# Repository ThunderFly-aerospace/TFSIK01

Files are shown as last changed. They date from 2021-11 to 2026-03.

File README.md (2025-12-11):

# TFSIK01 - Dual Antenna diversity telemetry modem with a high noise immunity

The TFSIK01 is a high-end open-source hardware design of a UAV modem utilizing [SiK firmware](https://github.com/ThunderFly-aerospace/SiK). It uses the latest Si1000 series chip Si1060, which is equipped with [Si4463 EZRadioPRO Transceiver](https://www.silabs.com/documents/public/data-sheets/Si4463-61-60-C.pdf).
The RF front-end is designed to have high immunity to jamming using the out-of-band frequencies. This gives TFSIK special features such as being operable in the  proximity of out-of-band signal jammers.  RF noise immunity is a hardware-based feature; therefore, it is extremely reliable, but the proper antenna and frequency band must be used for the best results. Please contact [ThunderFly s.r.o.](https://www.thunderfly.cz/) to get support and consultation.

TFSIK01 modem

## Where could I get it?  

The device can be purchased directly from [ThunderFly s.r.o.](https://www.thunderfly.cz/). Contact us by email at sale@thunderfly.cz for commercial support (Manufacturing aid, Licensing, RF verification, certification, etc.). We are the primary designers of this modem hardware and major Si1060 firmware contributors, and therefore, we can react even to non-standard requests for modification or functions (RF-band, output power, jamming resistance, etc.). The TFSIK is also available at the [Tindie](https://www.tindie.com/products/34682/) or [Lectronz](https://lectronz.com/products/1067) store in the most standard configurations. 

## The TFSIK features

   * Small size and Lightweight (under 20 grams without antenna)
   * Automatic antenna switching
   * Transparent serial link
   * Air data rates up to 250kbps
   * MAVLink protocol framing and status reporting
   * Frequency-hopping spread spectrum (FHSS)
   * Adaptive time division multiplexing (TDM)
   * Support for listening before talk (LBT) and Adaptive Frequency Agility (AFA)
   * Demonstrated a range of several kilometers with a small whip antenna
   * [Open source firmware]((https://github.com/ThunderFly-aerospace/SiK))
     * AT commands for local radio configuration
     * RT commands for remote radio configuration
     * Supported protocol: [MAVLink 2](https://en.wikipedia.org/wiki/MAVLink) or transparent serial.
     * Configurable duty cycle
     * Built-in error correcting code (can correct up to 25% of data bit errors)
   * Supported bands: 433MHz, 868 MHz. (Other frequencies are available upon request)
   * Interface: Pixhawk-compatible JST-GH UART link

 ## Advanced technologies used

  * Transceiver chip: Si4463
    * User-selectable output power up to +20 dBm (100mW) (The maximum legally allowed power output for most [ISM bands](https://en.wikipedia.org/wiki/ISM_radio_band))
    * RX Sensitivity -124 dBm @ 1000 bps FSK
  * MIMO 2x2 RX/TX: Two antenna diversity
    * Two separated [MCX connectors](https://en.wikipedia.org/wiki/MCX_connector) RX and TX on the each connector
  * RF switch: SPDT High Power UltraCMOS 10 MHz - 3 GHz
  * RF input low noise amplifier
    * 50MHz to 4000MHz, GaAs pHEMT SPF5189
    * Noise Figure 0.60dB
    * High noise immunity OIP3 39.5dBm
    * Gain 18.7dB
  * Filter: SAW AFS selected for the used frequency band

The above parameters are guaranteed only in the case of the use of a proper RF antenna matched for a given frequency band. When using an improper antenna with a radio modem, several issues may arise that could affect the performance, efficiency, and reliability of the system. Here is a simplified list:

  - **Reduced Range** - The most immediate problem would be a reduced operating range. The antenna is critical for transmitting and receiving signals effectively. An improper antenna may result in weaker signals, thereby limiting the distance over which the modem can communicate.
  - **Signal Degradation** - Poorly matched antennas could degrade the quality of the transmitted and received signals. This can lead to higher bit error rates, packet loss, and data corruption, impacting the reliability of the system.
  - **Increased Interference** - The wrong type or tuning of the antenna might pick up or transmit on unintended frequencies, causing interference with other systems or devices. This could be particularly problematic in crowded or jammed frequency bands.
  - **Power Imbalance** - The impedance mismatch between the antenna and the modem can result in a portion of the signal being reflected into the modem. This can potentially damage the modem’s internal components over time due to the stress on the components.
  - **Non-Compliance** - Using an improper antenna may lead to non-compliance with regulatory standards, which could result in legal issues or fines. Regulations often specify the types of antennas that can be used with particular types of modems or in specific frequency bands.
  - **Energy Inefficiency** - A mismatched antenna can be energy-inefficient, drawing more power than necessary to achieve a given range or data rate. This could be particularly problematic in battery-powered applications.
  - **Increased Latency** - Poor signal strength and quality could also result in increased latency due to packet retransmissions, affecting real-time applications like telemetry transmission.
  - **Difficulty in Troubleshooting** - An improper antenna can introduce a myriad of issues that can be hard to diagnose. This could result in increased downtime and maintenance costs, as engineers would need to spend additional time identifying and resolving the issues.

## Hardware

The TFSIK modem is enclosed in a 3D-printed box suitable for user modification. Inside that box are electronics with electromagnetic shielding.  

### TFSIK modem electronics

Here is a photo of TFSIK electronics with the essential electromagnetic shielding cover removed.

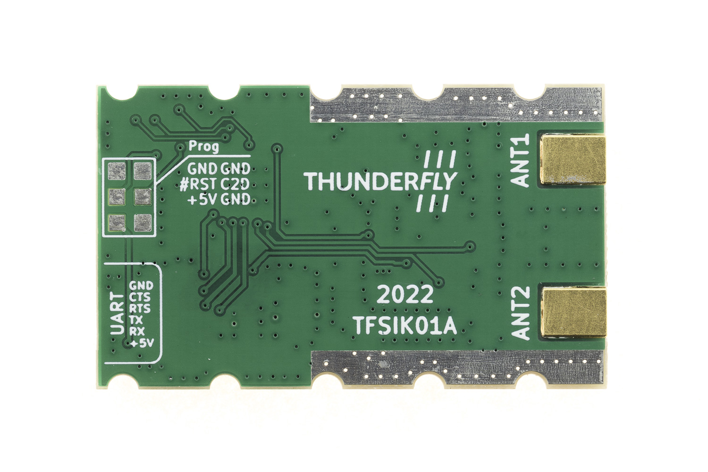
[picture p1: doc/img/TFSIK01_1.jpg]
TFSIK01A bottom view

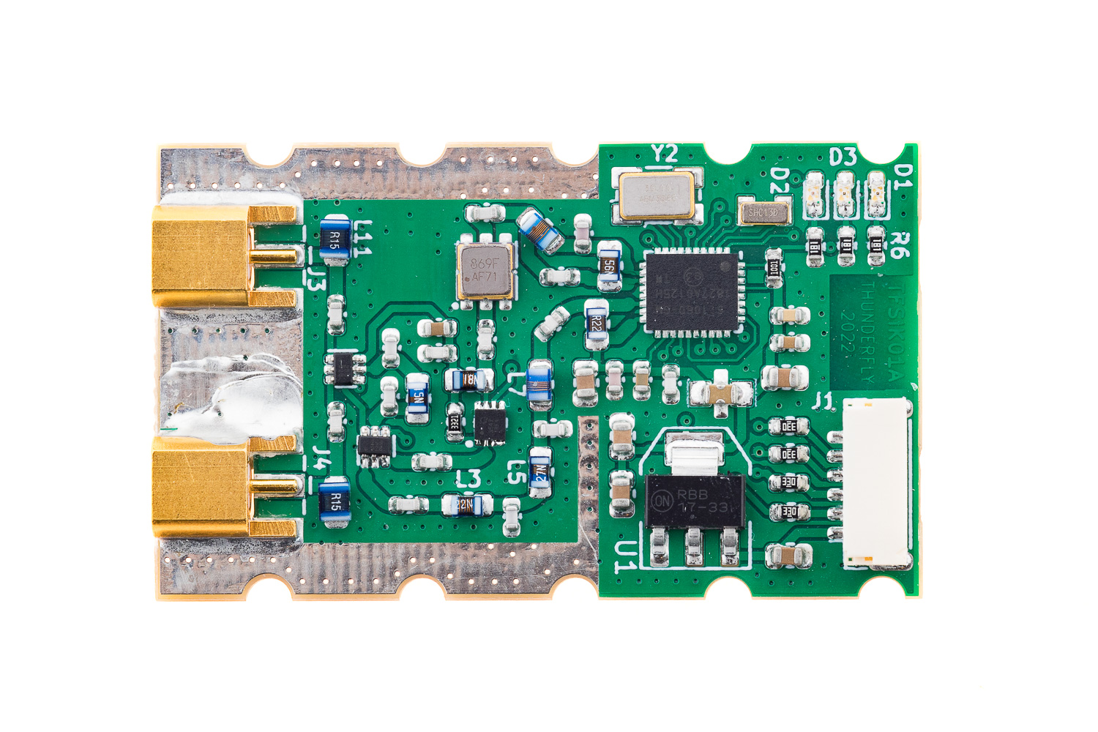
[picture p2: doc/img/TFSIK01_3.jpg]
TFSIK01A top view


### TFSIK antenna kit

External antennas are connected to the TFSIK modem by a pair of [MCX connectors](https://en.wikipedia.org/wiki/MCX_connector). For ease of use, we prepared a kit with simple whip antennas. This kit could be manufactured for multiple frequency bands. Here is 433 MHz as an example. The antenna kit strictly pairs only with the TFSIK modem tuned on the same frequency band.  

TFSIK01 antenna kit

As you can see, the antenna kit contains two asymmetrically mounted antennas. The antenna is tightened in position by SMA connectors. The optimal position depends on your exact setup, but generally, the antennae should be orthogonal to each other due to their "donut" radiation patterns.
The whole setup of TFSIK01 with the antenna kit should be mounted by a pair of screws in the holes of the antenna kit.

## Usage examples

### UAV command and control

The TFSIK modem is intended to be used at the UAV as an "in the air" part of the communication link. For the ground control station, the [TFMODEM](https://github.com/ThunderFly-aerospace/TFMODEM01) is supposed to be used.  
The reasons for the difference in the air and ground control station units are design tradeoffs.  
For example, the ground control unit needs a very reliable interface; therefore, there is a large interface USB connector to the ground control station computer. The same connector is impractical to use in the UAV part. Similar restrictions apply to the RF filters, antenna connectors, etc. To resolve that, we decided to use different implementations of the ground station.

### ROS2 long-range wireless datalink

SiK firmware is commonly used in radio modems, particularly in the fields of unmanned aerial vehicles (UAVs) and robotics. When integrated into a Robot Operating System (ROS) or ROS2 environment, SiK technology offers several advantages. It provides reliable and long-range communication, which is crucial for both indoor and outdoor robotic applications. The low latency of TFSIK01 modems ensures real-time responsiveness, a critical factor in robotics. These modems are highly configurable, offering users the flexibility to tailor the system according to specific needs. Additionally, their compatibility with various communication protocols makes them easy to integrate into existing ROS and ROS2 systems.

More details about the [TFSIK01 telemetry modem can be found on ThunderFly's documentation website](https://docs.thunderfly.cz/avionics/TFSIK01/).

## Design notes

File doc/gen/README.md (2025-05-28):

# PCB

Board size: 50.0x30.0 mm (1.97x1.18 inches)

- This is the size of the rectangle that contains the board
- Thickness: 1.6 mm (63 mils)
- Material: FR4
- Finish: None
- Layers: 2
- Copper thickness: 35 µm

Solder mask: TOP / BOTTOM

- Color: Green

Silk screen: TOP / BOTTOM

- Color: White

Stackup:

| Name | Type | Color | Thickness [µm]| Material | Er | Loss tan |
|---|---|---|---|---|---|---|
| F.SilkS | Top Silk Screen | | | | | |
| F.Mask | Top Solder Mask | Green | 10 | | | |
| F.Cu | copper | | 35 | | | |
| dielectric 1 | core | | 1510 | FR4 | 4.5 | 0.020 |
| B.Cu | copper | | 35 | | | |
| B.Mask | Bottom Solder Mask | Green | 10 | | | |
| B.Paste | Bottom Solder Paste  | | | | | |
| B.SilkS | Bottom Silk Screen | | | | | |

# Important sizes

Clearance: 0.2 mm (8 mils)

Track width: 0.2 mm (8 mils)

- By design rules: 0.2 mm (8 mils)

Drill: 0.3 mm (12 mils)

- Vias: 0.5 mm (20 mils) [Design: 0.4 mm (16 mils)]
- Pads: 0.3 mm (12 mils)
- The above values are real drill sizes, they add 0.1 mm (4 mils) to plated holes (PTH)

Via: 0.8/0.4 mm (31/16 mils)

- By design rules: 0.4/0.3 mm (16/12 mils)
- Micro via: yes [0.2/0.1 mm (8/4 mils)]
- Buried/blind via: yes
- Total: 237 (thru: 237 buried/blind: 0 micro: 0)

Outer Annular Ring: 0.1 mm (4 mils)

- By design rules: 0.1 mm (4 mils)

Eurocircuits class: 6D
- Using min drill 0.25 mm for an OAR of 0.13 mm

# General stats

Components count: (SMD/THT)

- Top: 0/11 (THT)
- Bottom: 56/3 (SMD + THT)

Defined tracks:

- 0.2 mm (8 mils)
- 0.3 mm (12 mils)
- 0.4 mm (16 mils)
- 0.5 mm (20 mils)
- 0.6 mm (24 mils)
- 0.8 mm (31 mils)
- 0.86 mm (34 mils)

Used tracks:

- 0.2 mm (8 mils) (100) defined: yes
- 0.3 mm (12 mils) (73) defined: yes
- 0.4 mm (16 mils) (49) defined: yes
- 0.5 mm (20 mils) (27) defined: yes
- 0.6 mm (24 mils) (21) defined: yes
- 0.86 mm (34 mils) (71) defined: yes

Defined vias:

Used vias:

- 0.8/0.4 mm (31/16 mils) (Count: 237, Aspect: 2.0 A) defined: no

Holes (excluding vias):

- 0.2 mm (8 mils) (15)
- 0.3 mm (12 mils) (4)
- 3.0 mm (118 mils) (10)

Oval holes:

Drill tools (including vias and computing adjusts and rounding):

- 0.3 mm (12 mils) (15)
- 0.4 mm (16 mils) (4)
- 0.5 mm (20 mils) (237)
- 3.0 mm (118 mils) (10)

Solder paste stats:

Using a paste with 87.75 % alloy, that has an specific gravity for the alloy of 7.4 g/cm³
and 1.0 g/cm³ for the flux. This paste has an specific gravity of  4.15 g/cm³.

The stencil thickness is  0.12 mm.

| Side | Pads with paste | Area [mm²] | Paste [g] |
|---|---|---|---|
| Top | 6 | 13.94 | 0.07 |
| Bottom | 186 | 176.22 | 0.88 |
| Total  | 192 | 190.16 | 0.95 |

Note: this is just an approximation to the theoretical value. Margins of the solder mask and waste aren't computed.

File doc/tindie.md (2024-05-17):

TFSIK01A is a high-end, open-source UAV telemetry modem designed for superior noise immunity and reliable performance. This modem, built with the latest Si1060 chip and Si4463 EZRadioPRO Transceiver, ensures optimal operation even in the presence of signal jammers. Perfect for UAV enthusiasts and professionals alike, the TFSIK01A is your go-to for seamless and robust communication.

## Key Features

- **High Noise Immunity**: Operates reliably near out-of-band  signal jammers.
- **Dual Antenna Diversity**: Automatic antenna switch for optimal signal strength.
- **Lightweight & Compact**: Weighs under 20 grams without antennas.
- **High Data Rates**: Supports air data rates up to 250kbps.
- **Long Range**: Demonstrated range of several kilometers with a small whip antenna.
- **Advanced Protocols**: Includes MAVLink protocol framing, frequency-hopping spread spectrum (FHSS), and adaptive time division multiplexing (TDM).
- **Open Source**: Fully configurable with AT and RT commands. Compatible with Pixhawk via JST-GH UART link.
- Backward compatible with other SiK firmware based modems
- **Multiple Frequency Bands**: Available in 433MHz and 868MHz, with custom frequencies upon request.

## Advanced Technologies

- **Si4463 Transceiver Chip**: User-selectable output power up to +20 dBm, RX sensitivity -124 dBm @ 1000 bps FSK.
- **MIMO 2x2 RX/TX**: Two antenna diversity with separate MCX connectors for RX and TX.
- **RF Switch & Low Noise Amplifier**: Ensures high noise immunity and optimal performance.

## Applications

- **UAV Command and Control**: Ideal for use in UAVs, paired with another SiK-based modem for ground control stations.
- **ROS2 Wireless Datalink**: Provides reliable, long-range communication for robotics, ensuring real-time responsiveness and easy integration with ROS and ROS2 systems.

## Why Choose TFSIK01A?

The TFSIK01A modem offers unmatched performance and flexibility for UAV communication needs. Its robust design, advanced features, and open-source firmware make it a versatile choice for both hobbyists and professionals. Plus, with support from ThunderFly, you can get customized solutions tailored to your specific requirements.

## What's Included 

- Pair of TFSIK01 electronics with RF shielding and housing
- [TFUSBSERIAL01](https://docs.thunderfly.cz/avionics/TFUSBSERIAL01/) - USB-C to serial converter for ground control station connection
- Two 15cm serial cables with JST-GH connectors
- Pair of Antenna kit (optional)

> The product is assembled and ready to use.

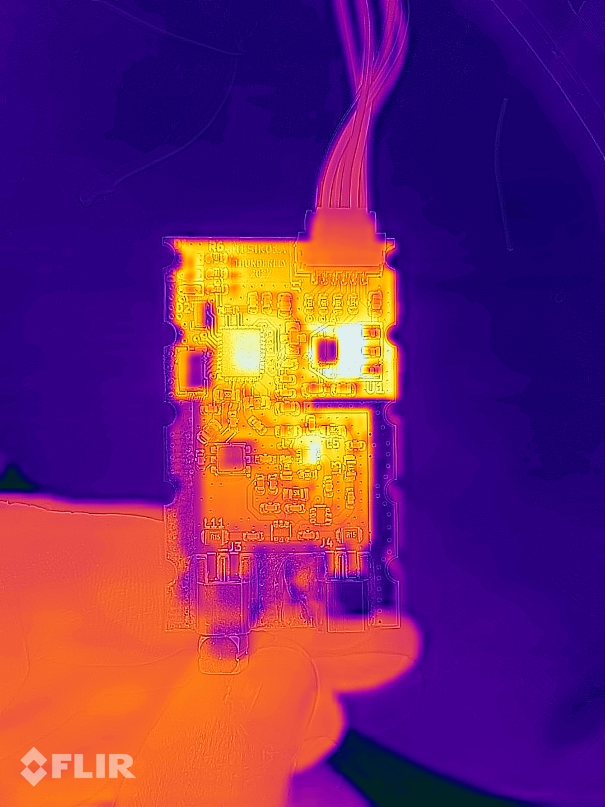
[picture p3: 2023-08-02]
doc/img/TFSIK01A_heat_dissipation.jpg

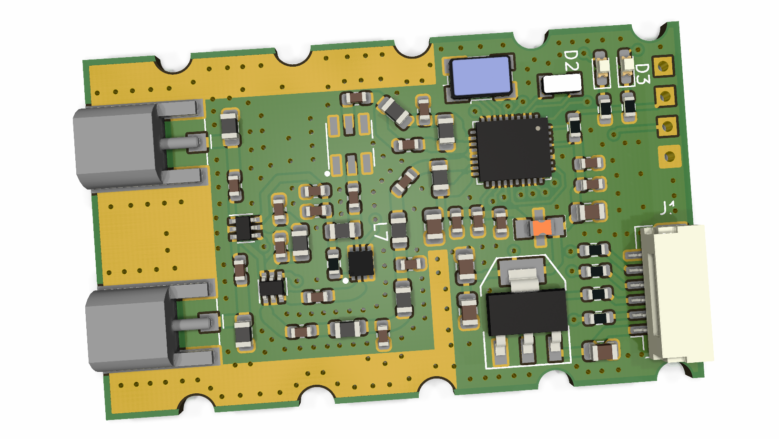
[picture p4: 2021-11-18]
doc/img/TFSIK01A_render_top.png

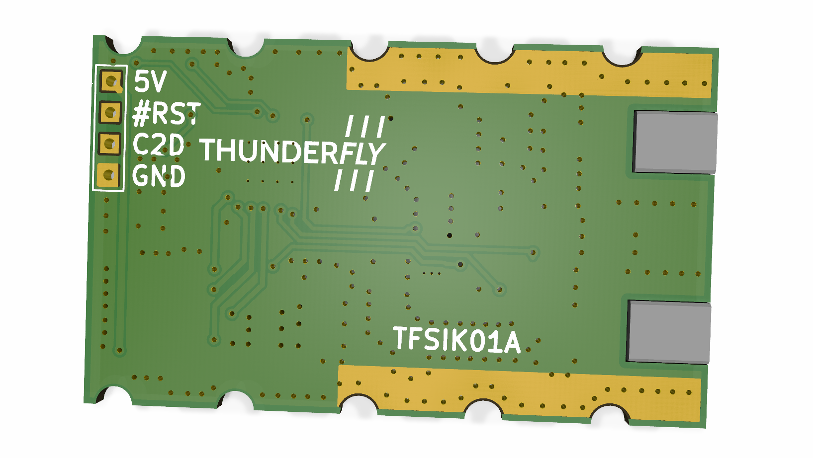
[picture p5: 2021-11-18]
doc/img/TFSIK01A_render_bottom.png

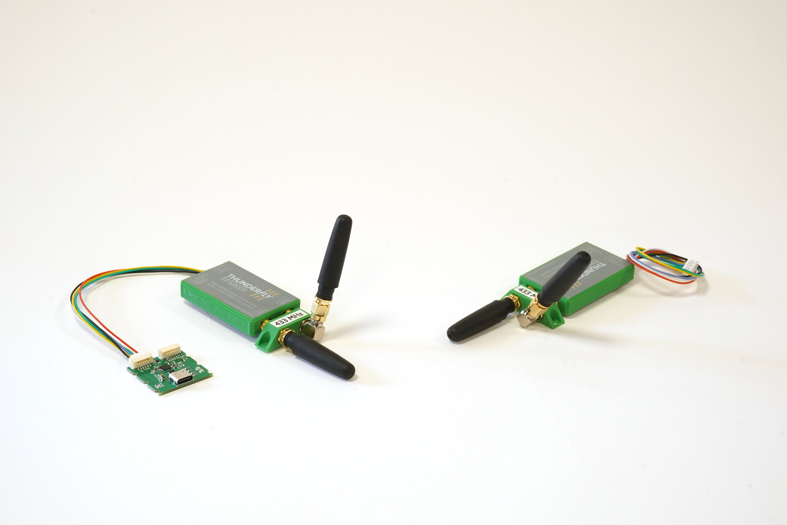
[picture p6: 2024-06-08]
doc/img/TFSIK01_pair.jpg

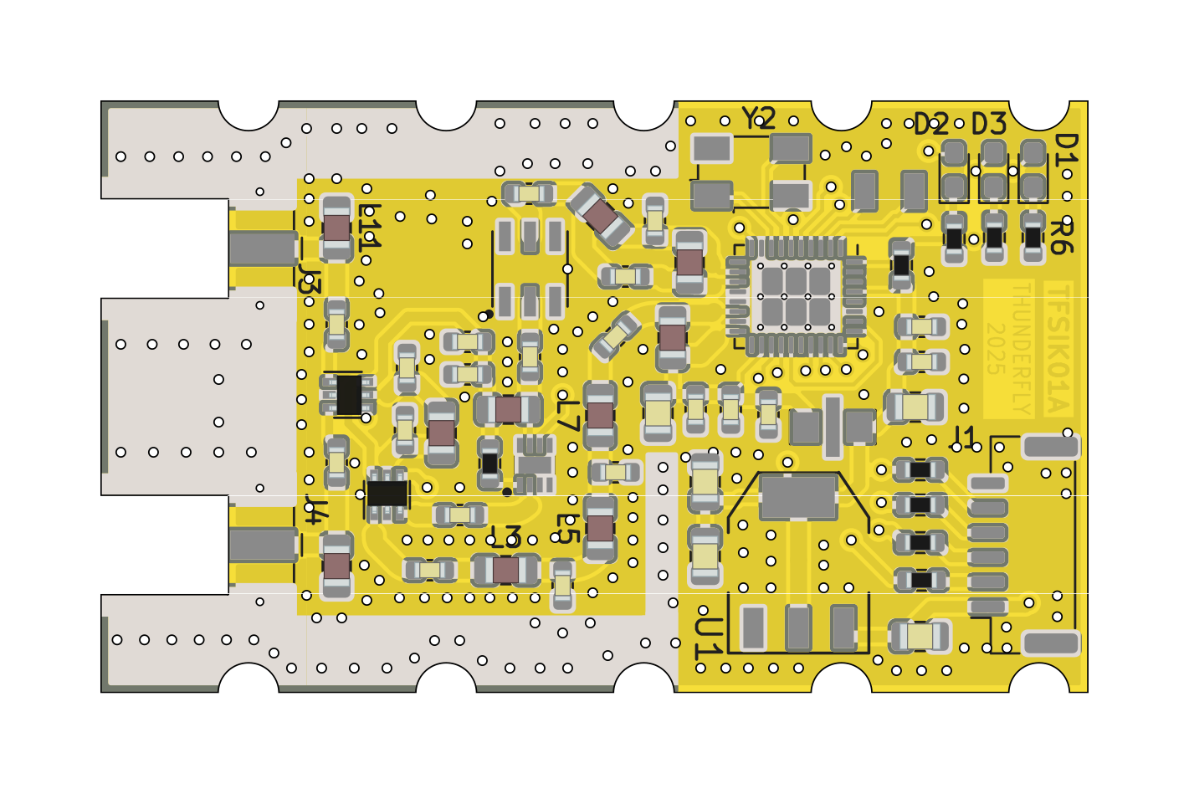
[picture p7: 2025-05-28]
doc/gen/img/TFSIK01-bottom.png

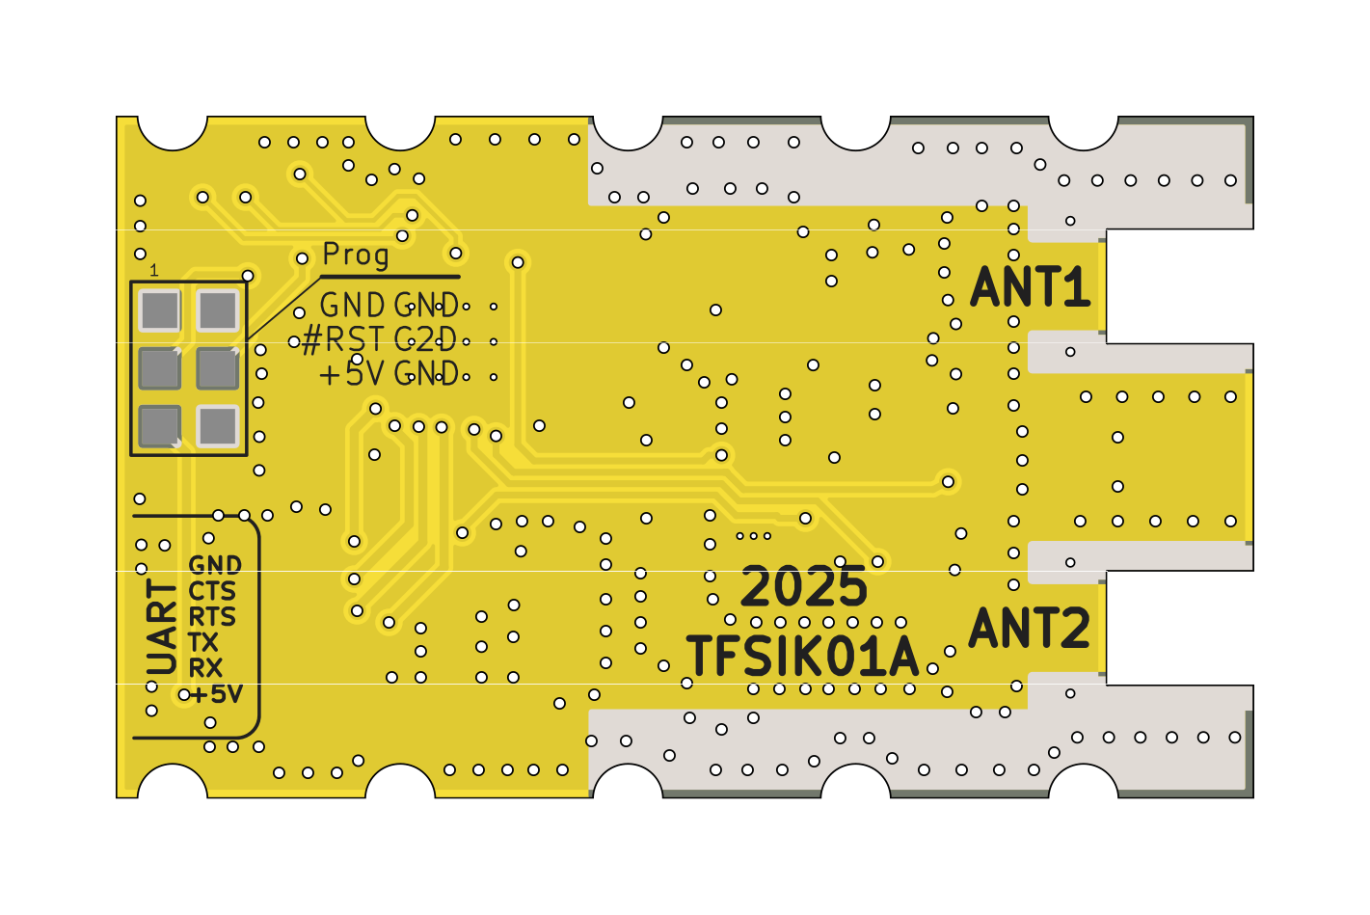
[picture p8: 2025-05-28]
doc/gen/img/TFSIK01-top.png

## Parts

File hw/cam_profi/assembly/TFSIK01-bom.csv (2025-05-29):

Component | Description | Part | References | Value | Footprint | Quantity Per PCB | Datasheet | ust_id_433 | value_868 | ust_id_868 | value_433 | ust_id
1 | Unpolarized capacitor, small symbol | C_Small | C7C28C29 | 9.1pF | C_0603_1608Metric | 3 | ~ | 611b60e71287500165a9732d 5c70984812875079b91f8be2 | 2.7pF 4.7pF | 5c70984812875079b91f8bde 5c70984812875079b91f8be0
2 | Unpolarized capacitor, small symbol | C_Small | C9 | 13pF | C_0603_1608Metric | 1 | ~ | 5c70984812875079b91f8be4 | 5.1pF | 67d2108dee7fc534862c3c29 | 15pF
3 | Unpolarized capacitor, small symbol | C_Small | C15 | 33pF | C_0603_1608Metric | 1 | ~ |  |  |  |  | 5c70984812875079b91f8be7
4 | Unpolarized capacitor, small symbol | C_Small | C11 | 8,2pF | C_0603_1608Metric | 1 | ~ | 611b60e71287500165a9732d | 3.9pF | 5c70984812875079b91f8bdf | 9.1pF
5 | Unpolarized capacitor, small symbol | C_Small | C2C4C17C26C27C31C33C34 | 100pF | C_0603_1608Metric | 8 | ~ |  |  |  |  | 5c70984812875079b91f8bea
6 | Unpolarized capacitor, small symbol | C_Small | C14 | 10nF | C_0603_1608Metric | 1 | ~ |  |  |  |  | 5c70984812875079b91f8bef
7 | Unpolarized capacitor, small symbol | C_Small | C16C19 | 100nF | C_0603_1608Metric | 2 | ~ |  |  |  |  | 5c70984812875079b91f8bf2
8 | Unpolarized capacitor | C | C32 | 1uF | C_0603_1608Metric | 1 | ~ |  |  |  |  | 5c70984812875079b91f8bc2
9 | Unpolarized capacitor, small symbol | C_Small | C1C3C5C18C20 | 10uF | C_0805_2012Metric | 5 | ~ |  |  |  |  | 5c70984812875079b91f8bbe
10 | EMI filter, single capacitor | Filter_EMI_C | C21 | NFM21PC105 | FIR_0805 | 1 | http://www.murata.com/~/media/webrenewal/support/library/catalog/products/emc/emifil/c31e.ashx?la=en-gb |  |  |  |  | 5c70984412875079b91f880f
11 | Unpolarized capacitor, small symbol | C_Small | C12C13 | ~ | C_0603_1608Metric | 2 | ~ | 5c70984812875079b91f8bdd 5c70984812875079b91f8be0 | 1pF 3pF | 64c9689576c82a1d3b5794ae 64c96d7f76c82a1d3b57951d | 2.2pF 4.7pF
12 | Light emitting diode | LED | D3 | GREEN | LED_0603_1608Metric_Pad1.05x0.95mm_HandSolder | 1 | ~ |  |  |  |  | 60d582331287500165f859d0
13 | Light emitting diode | LED | D1D2 | RED | LED_0603_1608Metric_Pad1.05x0.95mm_HandSolder | 2 | ~ |  |  |  |  | 60d581db1287500165f859a2
14 | Dielectric Band Pass Filter for 1575MHz | SAW_AFS434S3-T_AFS869S3-T | FL1 | ~ | ABRACON_AFS | 1 |  | 5fd09b1b1287507e2b223689 | AFS869S3-T | 5c70984712875079b91f8b19 | AFS434S3-T
15 |  | SMA | J3J4 | MCX 73415-1061 | MCX_Molex_73415-1061 | 2 |  |  |  |  |  | 611b66b31287500165a973eb
16 | 1x07 2.54 mm pitch header | SM06B-GHS-TB | J1 | SM06B-GHS-TB | JST_GH_SM06B-GHS-TB_1x06-1MP_P1.25mm_Horizontal | 1 |  |  |  |  |  | 5fa0f70212875025b3977932
17 | Inductor | L | L13 | 15nH | L_0805_2012Metric_Pad1.15x1.40mm_HandSolder | 1 | ~ | 67d2e046ee7fc534862c3d3f | 9.1nH | 67d2e5b6ee7fc534862c3da0
18 | Inductor | L | L16 | 18nH | L_0805_2012Metric_Pad1.15x1.40mm_HandSolder | 1 | ~ |  |  |  |  | 5c70984412875079b91f8806
19 | Inductor, small symbol | L_Small | L3 | 22nH | L_0805_2012Metric_Pad1.15x1.40mm_HandSolder | 1 | ~ | 60be80ed1287500165e6c3bb | 11nH | 67d2af9bee7fc534862c3cc3
20 | Inductor, small symbol | L_Small | L5 | 27nH | L_0805_2012Metric_Pad1.15x1.40mm_HandSolder | 1 | ~ | 5c70984412875079b91f8807 | 11nH | 67d2af9bee7fc534862c3cc3
21 | Inductor, small symbol | L_Small | L7 | 30nH | L_0805_2012Metric_Pad1.15x1.40mm_HandSolder | 1 | ~ | 5c70984412875079b91f8808 | 15nH | 5cd08bde128750448e4542d8 | 33nH
22 | Inductor | L | L11L12 | 150nH | L_0805_2012Metric_Pad1.15x1.40mm_HandSolder | 2 | ~ |  |  |  |  | 611b63ba1287500165a97381
23 | Inductor, small symbol | L_Small | L8L9L10 | ~ | L_0805_2012Metric_Pad1.15x1.40mm_HandSolder | 3 | ~ | 5c70984412875079b91f880d 5c70984812875079b91f8ba4 64c92bf976c82a1d3b57944c | 120nH 24nH | 68383c16ee7fc534862c70da 652daa63462c6d9e72055f5e 64c969b476c82a1d3b5794d8 | 220nH 56nH 62nH
24 |  | HOLE_TF | M1M2M3M4M5M6M7M8M9M10 | HOLE_TF | dira_3mm | 10
25 | Resistor | R | R1R2R3R4 | 33R | R_0603_1608Metric | 4 | ~ |  |  |  |  | 5c70984512875079b91f8952
26 | Resistor | R | R6R22R23 | 180R | R_0603_1608Metric | 3 | ~ |  |  |  |  | 5c70984512875079b91f8957
27 | Resistor | R | R20 | 1k | R_0603_1608Metric | 1 | ~ |  |  |  |  | 5c70984512875079b91f895c
28 | Resistor | R | R5 | 3k32 | R_0603_1608Metric | 1 | ~ |  |  |  |  | 611b6b921287500165a97468
29 |  | LM1117 | U1 | LM1117-3V3 | SOT-223 | 1 |  |  |  |  |  | 5c70984712875079b91f8af9
30 | RF Switch | PE4259 | U7U9 | PE4259 | SOT-363_SC-70-6 | 2 | https://www.psemi.com/pdf/datasheets/pe4259ds.pdf |  |  |  |  | 5face19b12875025b3977e15
31 |  | QPL9547 | U3 | QPL9547 | SON50P200X200X95-9N-D | 1 | https://www.qorvo.com/products/p/QPL95474 |  |  |  |  | 611b78331287500165a97491
32 |  | Si1060-A-GM | U2 | Si1060-A-GM | QFN-36-1EP_5x6mm_P0.5mm_EP3.6x4.1mm_ThermalVias | 1 | https://www.silabs.com/documents/public/data-sheets/Si106x-8x.pdf |  |  |  |  | 5c70984812875079b91f8ba3
33 | Two pin crystal | Crystal | Y1 | ABS07-120-32.768KHZ | ABS07 | 1 | ~ |  |  |  |  | 5c70984712875079b91f8b1b
34 | Four pin crystal, GND on pins 2 and 4 | Crystal_GND24 | Y2 | ~ | Crystal_SMD_Abracon_ABM3B-4Pin_5.0x3.2mm | 1 | ~ | 5c70984712875079b91f8ba1 | ECS-260-8-30B-CKM | 64c9715d76c82a1d3b579549 | ABM3B-30.000MHZ-10-1-U-T

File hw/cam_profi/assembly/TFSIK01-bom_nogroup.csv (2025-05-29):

Component | Description | Part | References | Value | Footprint | Quantity Per PCB | Datasheet | ust_id_433 | value_868 | ust_id_868 | value_433 | ust_id
1 | Unpolarized capacitor | C | C28 | 9.1pF | C_0603_1608Metric | 1 | ~ | 5c70984812875079b91f8be2 | 4.7pF | 5c70984812875079b91f8be0
2 | Unpolarized capacitor | C | C29 | 9.1pF | C_0603_1608Metric | 1 | ~ | 5c70984812875079b91f8be2 | 4.7pF | 5c70984812875079b91f8be0
3 | Unpolarized capacitor, small symbol | C_Small | C7 | 9.1pF | C_0603_1608Metric | 1 | ~ | 611b60e71287500165a9732d | 2.7pF | 5c70984812875079b91f8bde
4 | Unpolarized capacitor, small symbol | C_Small | C9 | 13pF | C_0603_1608Metric | 1 | ~ | 5c70984812875079b91f8be4 | 5.1pF | 67d2108dee7fc534862c3c29 | 15pF
5 | Unpolarized capacitor, small symbol | C_Small | C15 | 33pF | C_0603_1608Metric | 1 | ~ |  |  |  |  | 5c70984812875079b91f8be7
6 | Unpolarized capacitor, small symbol | C_Small | C11 | 8,2pF | C_0603_1608Metric | 1 | ~ | 611b60e71287500165a9732d | 3.9pF | 5c70984812875079b91f8bdf | 9.1pF
7 | Unpolarized capacitor, small symbol | C_Small | C17 | 100pF | C_0603_1608Metric | 1 | ~ |  |  |  |  | 5c70984812875079b91f8bea
8 | Unpolarized capacitor, small symbol | C_Small | C2 | 100pF | C_0603_1608Metric | 1 | ~ |  |  |  |  | 5c70984812875079b91f8bea
9 | Unpolarized capacitor | C | C26 | 100pF | C_0603_1608Metric | 1 | ~ |  |  |  |  | 5c70984812875079b91f8bea
10 | Unpolarized capacitor | C | C27 | 100pF | C_0603_1608Metric | 1 | ~ |  |  |  |  | 5c70984812875079b91f8bea
11 | Unpolarized capacitor | C | C31 | 100pF | C_0603_1608Metric | 1 | ~ |  |  |  |  | 5c70984812875079b91f8bea
12 | Unpolarized capacitor | C | C33 | 100pF | C_0603_1608Metric | 1 | ~ |  |  |  |  | 5c70984812875079b91f8bea
13 | Unpolarized capacitor | C | C34 | 100pF | C_0603_1608Metric | 1 | ~ |  |  |  |  | 5c70984812875079b91f8bea
14 | Unpolarized capacitor, small symbol | C_Small | C4 | 100pF | C_0603_1608Metric | 1 | ~ |  |  |  |  | 5c70984812875079b91f8bea
15 | Unpolarized capacitor, small symbol | C_Small | C14 | 10nF | C_0603_1608Metric | 1 | ~ |  |  |  |  | 5c70984812875079b91f8bef
16 | Unpolarized capacitor, small symbol | C_Small | C16 | 100nF | C_0603_1608Metric | 1 | ~ |  |  |  |  | 5c70984812875079b91f8bf2
17 | Unpolarized capacitor, small symbol | C_Small | C19 | 100nF | C_0603_1608Metric | 1 | ~ |  |  |  |  | 5c70984812875079b91f8bf2
18 | Unpolarized capacitor | C | C32 | 1uF | C_0603_1608Metric | 1 | ~ |  |  |  |  | 5c70984812875079b91f8bc2
19 | Unpolarized capacitor, small symbol | C_Small | C1 | 10uF | C_0805_2012Metric | 1 | ~ |  |  |  |  | 5c70984812875079b91f8bbe
20 | Unpolarized capacitor, small symbol | C_Small | C18 | 10uF | C_0805_2012Metric | 1 | ~ |  |  |  |  | 5c70984812875079b91f8bbe
21 | Unpolarized capacitor, small symbol | C_Small | C20 | 10uF | C_0805_2012Metric | 1 | ~ |  |  |  |  | 5c70984812875079b91f8bbe
22 | Unpolarized capacitor, small symbol | C_Small | C3 | 10uF | C_0805_2012Metric | 1 | ~ |  |  |  |  | 5c70984812875079b91f8bbe
23 | Unpolarized capacitor, small symbol | C_Small | C5 | 10uF | C_0805_2012Metric | 1 | ~ |  |  |  |  | 5c70984812875079b91f8bbe
24 | EMI filter, single capacitor | Filter_EMI_C | C21 | NFM21PC105 | FIR_0805 | 1 | http://www.murata.com/~/media/webrenewal/support/library/catalog/products/emc/emifil/c31e.ashx?la=en-gb |  |  |  |  | 5c70984412875079b91f880f
25 | Unpolarized capacitor, small symbol | C_Small | C12 | ~ | C_0603_1608Metric | 1 | ~ | 5c70984812875079b91f8bdd | 1pF | 64c9689576c82a1d3b5794ae | 2.2pF
26 | Unpolarized capacitor, small symbol | C_Small | C13 | ~ | C_0603_1608Metric | 1 | ~ | 5c70984812875079b91f8be0 | 3pF | 64c96d7f76c82a1d3b57951d | 4.7pF
27 | Light emitting diode | LED | D3 | GREEN | LED_0603_1608Metric_Pad1.05x0.95mm_HandSolder | 1 | ~ |  |  |  |  | 60d582331287500165f859d0
28 | Light emitting diode | LED | D1 | RED | LED_0603_1608Metric_Pad1.05x0.95mm_HandSolder | 1 | ~ |  |  |  |  | 60d581db1287500165f859a2
29 | Light emitting diode | LED | D2 | RED | LED_0603_1608Metric_Pad1.05x0.95mm_HandSolder | 1 | ~ |  |  |  |  | 60d581db1287500165f859a2
30 | Dielectric Band Pass Filter for 1575MHz | SAW_AFS434S3-T_AFS869S3-T | FL1 | ~ | ABRACON_AFS | 1 |  | 5fd09b1b1287507e2b223689 | AFS869S3-T | 5c70984712875079b91f8b19 | AFS434S3-T
31 |  | SMA | J3 | MCX 73415-1061 | MCX_Molex_73415-1061 | 1 |  |  |  |  |  | 611b66b31287500165a973eb
32 |  | SMA | J4 | MCX 73415-1061 | MCX_Molex_73415-1061 | 1 |  |  |  |  |  | 611b66b31287500165a973eb
33 | 1x07 2.54 mm pitch header | SM06B-GHS-TB | J1 | SM06B-GHS-TB | JST_GH_SM06B-GHS-TB_1x06-1MP_P1.25mm_Horizontal | 1 |  |  |  |  |  | 5fa0f70212875025b3977932
34 | Inductor | L | L13 | 15nH | L_0805_2012Metric_Pad1.15x1.40mm_HandSolder | 1 | ~ | 67d2e046ee7fc534862c3d3f | 9.1nH | 67d2e5b6ee7fc534862c3da0
35 | Inductor | L | L16 | 18nH | L_0805_2012Metric_Pad1.15x1.40mm_HandSolder | 1 | ~ |  |  |  |  | 5c70984412875079b91f8806
36 | Inductor, small symbol | L_Small | L3 | 22nH | L_0805_2012Metric_Pad1.15x1.40mm_HandSolder | 1 | ~ | 60be80ed1287500165e6c3bb | 11nH | 67d2af9bee7fc534862c3cc3
37 | Inductor, small symbol | L_Small | L5 | 27nH | L_0805_2012Metric_Pad1.15x1.40mm_HandSolder | 1 | ~ | 5c70984412875079b91f8807 | 11nH | 67d2af9bee7fc534862c3cc3
38 | Inductor, small symbol | L_Small | L7 | 30nH | L_0805_2012Metric_Pad1.15x1.40mm_HandSolder | 1 | ~ | 5c70984412875079b91f8808 | 15nH | 5cd08bde128750448e4542d8 | 33nH
39 | Inductor | L | L11 | 150nH | L_0805_2012Metric_Pad1.15x1.40mm_HandSolder | 1 | ~ |  |  |  |  | 611b63ba1287500165a97381
40 | Inductor | L | L12 | 150nH | L_0805_2012Metric_Pad1.15x1.40mm_HandSolder | 1 | ~ |  |  |  |  | 611b63ba1287500165a97381
41 | Inductor, small symbol | L_Small | L10 | ~ | L_0805_2012Metric_Pad1.15x1.40mm_HandSolder | 1 | ~ | 64c92bf976c82a1d3b57944c | 20nH | 64c969b476c82a1d3b5794d8 | 62nH
42 | Inductor, small symbol | L_Small | L8 | ~ | L_0805_2012Metric_Pad1.15x1.40mm_HandSolder | 1 | ~ | 5c70984412875079b91f880d | 120nH | 68383c16ee7fc534862c70da | 220nH
43 | Inductor, small symbol | L_Small | L9 | ~ | L_0805_2012Metric_Pad1.15x1.40mm_HandSolder | 1 | ~ | 5c70984812875079b91f8ba4 | 24nH | 652daa63462c6d9e72055f5e | 56nH
44 |  | HOLE_TF | M1 | HOLE_TF | dira_3mm | 1
45 |  | HOLE_TF | M10 | HOLE_TF | dira_3mm | 1
46 |  | HOLE_TF | M2 | HOLE_TF | dira_3mm | 1
47 |  | HOLE_TF | M3 | HOLE_TF | dira_3mm | 1
48 |  | HOLE_TF | M4 | HOLE_TF | dira_3mm | 1
49 |  | HOLE_TF | M5 | HOLE_TF | dira_3mm | 1
50 |  | HOLE_TF | M6 | HOLE_TF | dira_3mm | 1
51 |  | HOLE_TF | M7 | HOLE_TF | dira_3mm | 1
52 |  | HOLE_TF | M8 | HOLE_TF | dira_3mm | 1
53 |  | HOLE_TF | M9 | HOLE_TF | dira_3mm | 1
54 | Resistor | R | R1 | 33R | R_0603_1608Metric | 1 | ~ |  |  |  |  | 5c70984512875079b91f8952
55 | Resistor | R | R2 | 33R | R_0603_1608Metric | 1 | ~ |  |  |  |  | 5c70984512875079b91f8952
56 | Resistor | R | R3 | 33R | R_0603_1608Metric | 1 | ~ |  |  |  |  | 5c70984512875079b91f8952
57 | Resistor | R | R4 | 33R | R_0603_1608Metric | 1 | ~ |  |  |  |  | 5c70984512875079b91f8952
58 | Resistor | R | R22 | 180R | R_0603_1608Metric | 1 | ~ |  |  |  |  | 5c70984512875079b91f8957
59 | Resistor | R | R23 | 180R | R_0603_1608Metric | 1 | ~ |  |  |  |  | 5c70984512875079b91f8957
60 | Resistor | R | R6 | 180R | R_0603_1608Metric | 1 | ~ |  |  |  |  | 5c70984512875079b91f8957
61 | Resistor | R | R20 | 1k | R_0603_1608Metric | 1 | ~ |  |  |  |  | 5c70984512875079b91f895c
62 | Resistor | R | R5 | 3k32 | R_0603_1608Metric | 1 | ~ |  |  |  |  | 611b6b921287500165a97468
63 |  | LM1117 | U1 | LM1117-3V3 | SOT-223 | 1 |  |  |  |  |  | 5c70984712875079b91f8af9
64 | RF Switch | PE4259 | U7 | PE4259 | SOT-363_SC-70-6 | 1 | https://www.psemi.com/pdf/datasheets/pe4259ds.pdf |  |  |  |  | 5face19b12875025b3977e15
65 | RF Switch | PE4259 | U9 | PE4259 | SOT-363_SC-70-6 | 1 | https://www.psemi.com/pdf/datasheets/pe4259ds.pdf |  |  |  |  | 5face19b12875025b3977e15
66 |  | QPL9547 | U3 | QPL9547 | SON50P200X200X95-9N-D | 1 | https://www.qorvo.com/products/p/QPL95474 |  |  |  |  | 611b78331287500165a97491
67 |  | Si1060-A-GM | U2 | Si1060-A-GM | QFN-36-1EP_5x6mm_P0.5mm_EP3.6x4.1mm_ThermalVias | 1 | https://www.silabs.com/documents/public/data-sheets/Si106x-8x.pdf |  |  |  |  | 5c70984812875079b91f8ba3
68 | Two pin crystal | Crystal | Y1 | ABS07-120-32.768KHZ | ABS07 | 1 | ~ |  |  |  |  | 5c70984712875079b91f8b1b
69 | Four pin crystal, GND on pins 2 and 4 | Crystal_GND24 | Y2 | ~ | Crystal_SMD_Abracon_ABM3B-4Pin_5.0x3.2mm | 1 | ~ | 5c70984712875079b91f8ba1 | ECS-260-8-30B-CKM | 64c9715d76c82a1d3b579549 | ABM3B-30.000MHZ-10-1-U-T

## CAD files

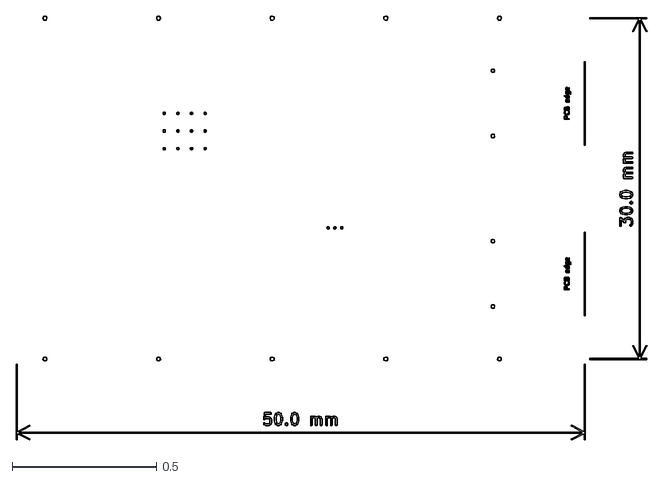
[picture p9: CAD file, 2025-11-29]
doc/gen/dxf/TFSIK01-User_Drawings.dxf
2.19 x 1.47

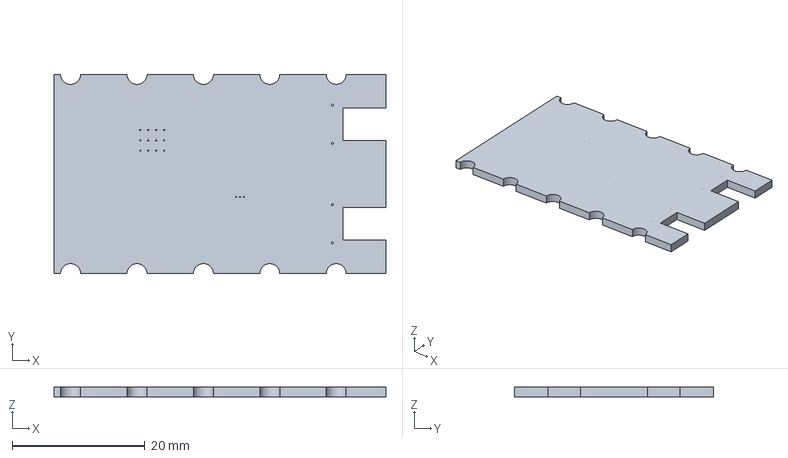
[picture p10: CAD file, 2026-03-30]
doc/gen/TFSIK01.step
50.0 x 30.0 x 1.51 mm

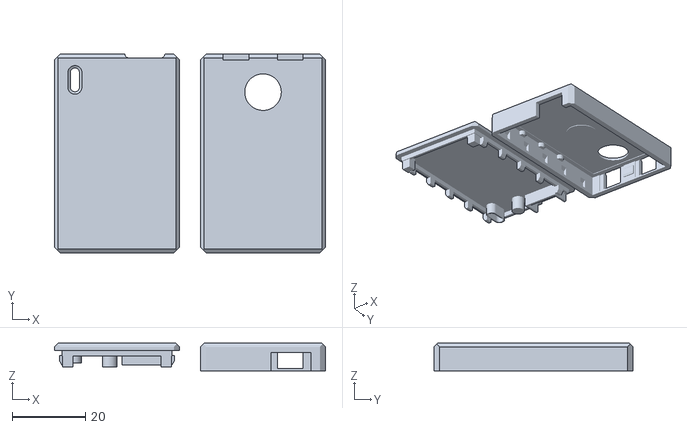
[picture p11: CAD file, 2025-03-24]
hw/cad/tfsik_box.stl
74.2 x 54.4 x 7.60

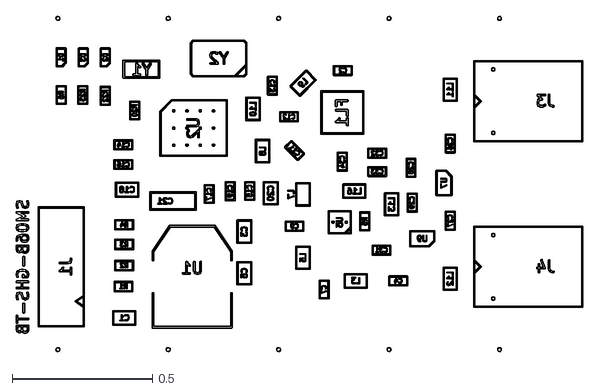
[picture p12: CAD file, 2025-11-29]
doc/gen/dxf/TFSIK01-B_Fab.dxf
2.02 x 1.19

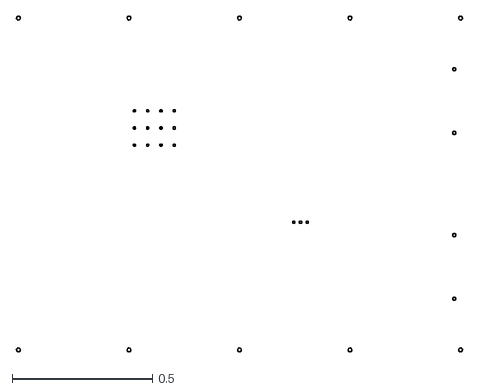
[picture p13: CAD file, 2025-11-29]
doc/gen/dxf/TFSIK01-F_Courtyard.dxf
1.59 x 1.19

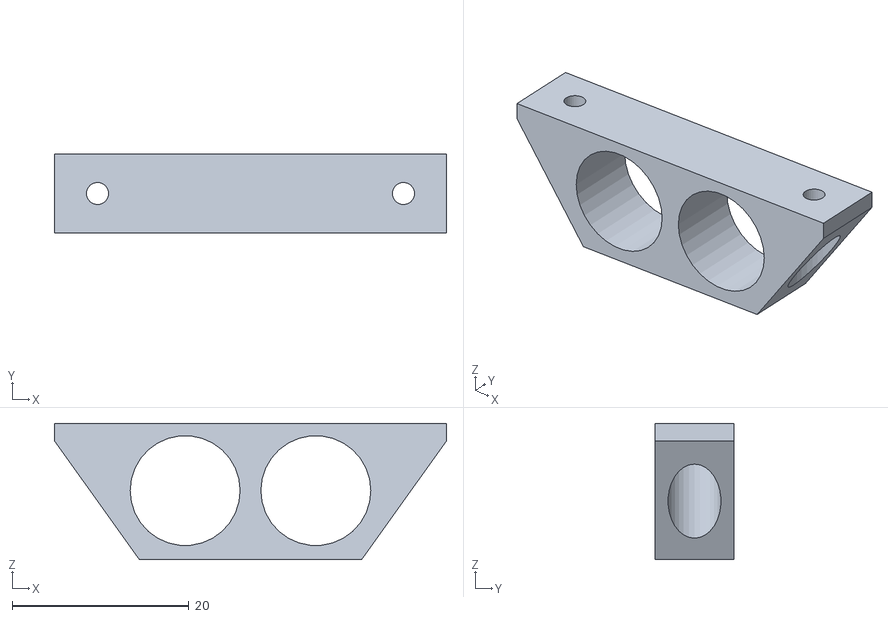
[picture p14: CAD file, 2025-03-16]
hw/cad/tfsik_antenna_holder_SMA_cylinder.stl
44.4 x 9.00 x 15.4

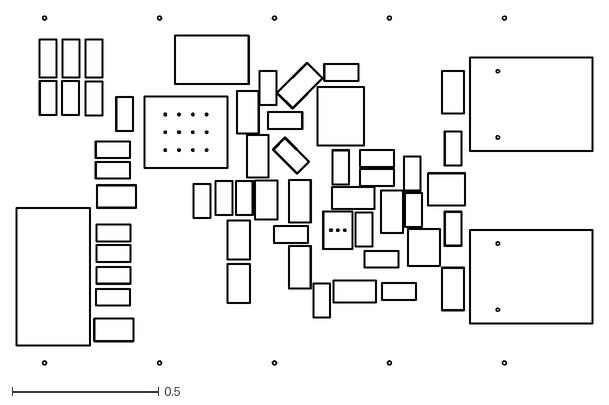
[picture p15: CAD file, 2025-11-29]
doc/gen/dxf/TFSIK01-B_Courtyard.dxf
1.98 x 1.19

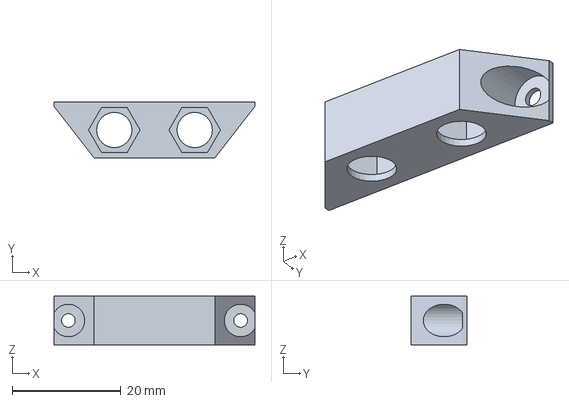
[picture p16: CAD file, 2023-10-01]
hw/cad/tfsik_antenna_holder.3mf
37.0 x 10.3 x 9.00 mm

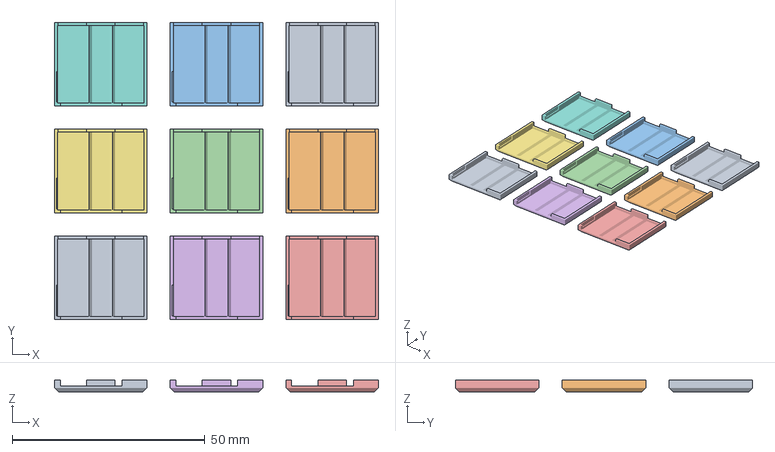
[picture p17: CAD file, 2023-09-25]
hw/cad/rf_shield.3mf
84.0 x 77.1 x 3.00 mm

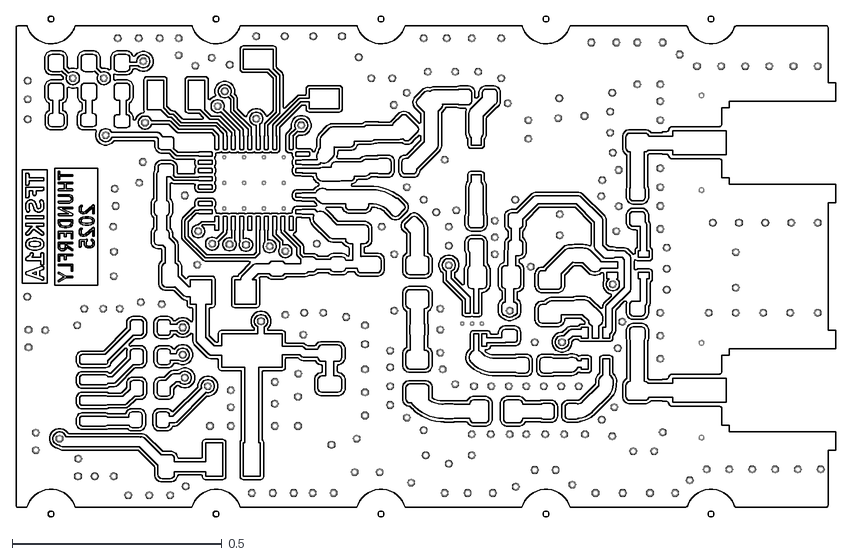
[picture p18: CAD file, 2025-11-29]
doc/gen/dxf/TFSIK01-B_Cu.dxf
1.95 x 1.19

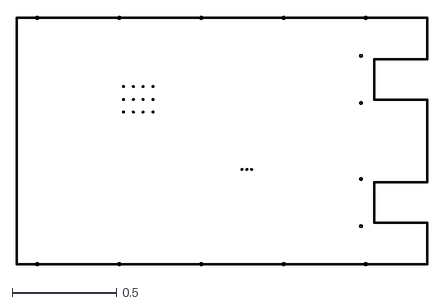
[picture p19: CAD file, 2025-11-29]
doc/gen/dxf/TFSIK01-Edge_Cuts.dxf
1.97 x 1.19

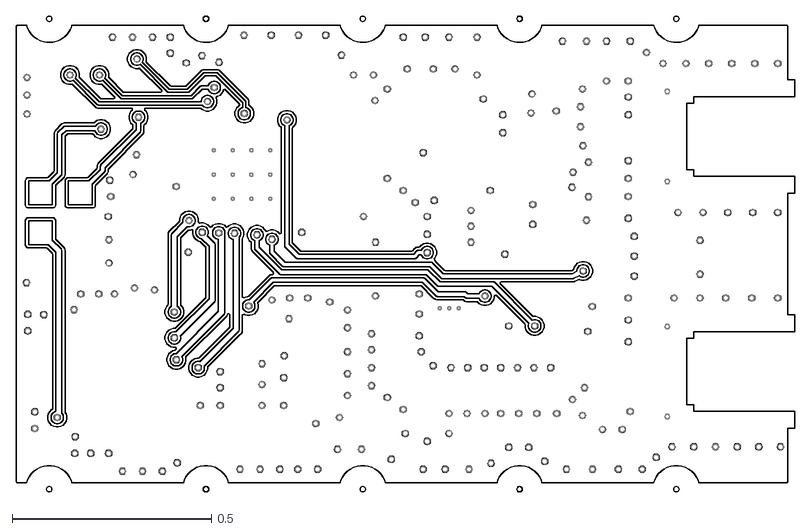
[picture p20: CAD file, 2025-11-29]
doc/gen/dxf/TFSIK01-F_Cu.dxf
1.95 x 1.19

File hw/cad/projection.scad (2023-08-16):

use<tfsik_box.scad>

projection(cut=true) translate([0, 0, 0]){
translate([40, 0, 0]) tfsik_box_top();
//tfsik_box_bottom();
}

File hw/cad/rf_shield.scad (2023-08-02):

module TFSIK_rf_shield(){
    width = 24;
    length = 21.7;
    depth = 3;
    wall = 0.8;
    
    roof_th = 0.7;

    difference(){
        translate([0, 0, depth/2]) cube([width, length, depth], center=true);
        
        difference(){
            translate([0, 0, depth/2-roof_th]) cube([width-2*wall, length-2*wall, depth], center=true);
        
        // vystuzeni
        
        //translate([0, length/2*0, depth-roof_th]) rotate([0, 90, 0]) cylinder(d=1, h=100, $fn=4, center=true);
        
        translate([width/2*0-3, 0, depth-roof_th]) rotate([90, 0, 0]) cylinder(d=1.4, h=length, $fn=4, center=true);
        translate([width/2*0+3, 0, depth-roof_th]) rotate([90, 0, 0]) cylinder(d=1.4, h=length, $fn=4, center=true);
        
        }
        
        //zkosene hrany
        translate([0, -length/2, depth]) rotate([0, 90, 0]) cylinder(d=2, h=100, $fn=4, center=true);
        translate([0, length/2, depth]) rotate([0, 90, 0]) cylinder(d=2, h=100, $fn=4, center=true);
        translate([-width/2, 0, depth]) rotate([90, 0, 0]) cylinder(d=2, h=100, $fn=4, center=true);
        translate([width/2, 0, depth]) rotate([90, 0, 0]) cylinder(d=2, h=100, $fn=4, center=true);
        
        
        // SMA connectors
        sma_dist = 15.2-0.4;
        sma_height = 1.5;
        sma_width = 7.4;
        sma_depth = 4;
        
        for(x=[-0.5*sma_dist, 0.5*sma_dist]) translate([x, -length/2, sma_height/2]) cube([sma_width, sma_depth*2, sma_height], center=true);
        
        // civky v zadni casti
        translate([-3.5+1, length/2, 1.5/2]) cube([16, 5, 1.5], center=true);
        
        // soucastky 
        translate([-4.5, length/2-4-1, 1.5/2]) cube([14, 8, 1.5], center=true);
        
    }
    
    



}


TFSIK_rf_shield();

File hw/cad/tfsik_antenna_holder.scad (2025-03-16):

mcx_dist = 15.2-0.4;
SMA_nut_d = 9.5;
SMA_cylinder_nut_d = 12.45;
SMA_screw_d = 6.5;
SMA_nut_l = 9;


jst_from_side = 2+0.5;

wall_side = 1;
layer_thickness = 0.2;
label_lenght = mcx_dist*2.5;
echo("Label space lenght:", label_lenght);

module tfsik_antenna_holder_SMA_hex(){

    difference(){
        hull(){
          translate([0, 0, -SMA_nut_d/2 - 2*layer_thickness]) cube([mcx_dist*1.5, SMA_nut_l, SMA_nut_d + 4*layer_thickness], center=true);
          translate([0, 0, -2*layer_thickness]) cube([label_lenght, SMA_nut_l, 4*layer_thickness], center=true);
        }

        // MCX

        for(x=[0.5*mcx_dist, -0.5*mcx_dist]) translate([x, 0, 0]){
            translate([0, -2, -SMA_nut_d/2 - 2*layer_thickness]) rotate([-90, 0, 0]) cylinder(d=SMA_screw_d, h=10, $fn=30);
            translate([0, -wall_side -SMA_nut_l/2, -SMA_nut_d/2 - 2*layer_thickness]) rotate([-90, 0, 0]) cylinder(d=SMA_nut_d, h=SMA_nut_l, $fn=6);
        }

        for(x=[0.5*(mcx_dist*1.5+SMA_nut_d), -0.5*(mcx_dist*1.5+SMA_nut_d)]) translate([x, 0, 0]){
            translate([0, 0, -6]) cylinder(d=2.5, h=10, $fn=30);
            translate([0, 0, -9 - 4*layer_thickness]) cylinder(d=6, h=SMA_nut_l, $fn=30);
        }

    }

}

//tfsik_antenna_holder_SMA_hex();


module tfsik_antenna_holder_SMA_cylinder(){

    difference(){
        hull(){
          translate([0, 0, -SMA_cylinder_nut_d/2 - 5*layer_thickness]) cube([mcx_dist*1.7, SMA_nut_l, SMA_cylinder_nut_d + 10*layer_thickness], center=true);
          translate([0, 0, 0]) cube([label_lenght*1.2, SMA_nut_l, 10*layer_thickness], center=true);
        }

        // MCX

        for(x=[0.5*mcx_dist, -0.5*mcx_dist]) translate([x, 0, 0]){
            //translate([0, -2, -SMA_nut_d/2 - 2*layer_thickness]) rotate([-90, 0, 0]) cylinder(d=SMA_screw_d, h=10, $fn=30);
            translate([0, -SMA_nut_l, -SMA_cylinder_nut_d/2 - 2*layer_thickness]) rotate([-90, 0, 0]) cylinder(d=SMA_cylinder_nut_d, h=SMA_nut_l*2, $fn=30);
        }

        for(x=[0.5*(mcx_dist*1.5+SMA_cylinder_nut_d), -0.5*(mcx_dist*1.5+SMA_cylinder_nut_d)]) translate([x, 0, 0]){
            translate([0, 0, -6]) cylinder(d=2.5, h=10, $fn=30);
            translate([0, 0, -SMA_cylinder_nut_d - 4*layer_thickness]) cylinder(d=6, h=SMA_cylinder_nut_d, $fn=30);
        }

    }

}


translate([0, 0, 15])
    tfsik_antenna_holder_SMA_cylinder();

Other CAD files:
hw/cad/tf_box.3mf
hw/cad/tfsik_box.scad
doc/gen/dxf/TFSIK01-B_Mask.dxf
doc/gen/dxf/TFSIK01-B_Paste.dxf
doc/gen/dxf/TFSIK01-B_Silkscreen.dxf
doc/gen/dxf/TFSIK01-F_Mask.dxf
doc/gen/dxf/TFSIK01-F_Silkscreen.dxf
hw/cad/rf_shield.stl
hw/cad/tfsik_antenna_holder.stl

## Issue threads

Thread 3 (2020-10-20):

Vypínač sériové linky pro USB převodník

roman-dvorak, 2020-10-20:
Holybro modemy jako USB převodník využivají FTDI čip [FT230XS](https://www.ftdichip.com/Support/Documents/DataSheets/ICs/DS_FT230X.pdf). Před ním mají "vypínač" z logických členů [HC126](https://www.ti.com/lit/ds/symlink/sn74hc126.pdf) (přesnou součástku jsem nedohledal jedná se však o tuto řadu), který sériovou linku modemu s FTDI převodníkem propojí po připojení napájení z USB.

Schéma zapojení přepínače je na následjícím obrázku.
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

ChroustJan, 2021-04-25:
Možný typ přepínače: https://www.ti.com/lit/ds/symlink/ts3a44159.pdf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

kaklik, 2021-05-13:
Není lepší sem místo těch několika tranzistorů dát prostě invertor s 5V tolerantním vstupem?

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

Například tohle zřejmě zároveň nahradí i ty tranzistory u diod [MC74LCX06](https://www.onsemi.com/pdf/datasheet/mc74lcx06-d.pdf)

ChroustJan, 2021-05-13:
@kaklik nápad je to zajímavé. Ale pokud to dobře čtu, může to mít i 0,5 V nízký stav to mi přijde docela vysoko.

kaklik, 2021-05-13:
> @kaklik nápad je to zajímavé. Ale pokud to dobře čtu, může to mít i 0,5 V nízký stav to mi přijde docela vysoko.

Ano, samozřejmě.. To není překvapivé, je to vlastnost bipolárních tranzistorů. Například [tranzistor BC817](https://www.onsemi.com/pdf/datasheet/bc817-40w-d.pdf), který je tam osazený má tohle napětí až 0.7V a 0.5V je běžná hodnota.

ChroustJan, 2021-05-14:
Pokud to dobře chápu tak to napětí je závislé na proudech atd... A umí být u BC817 menší.

kaklik, 2021-05-14:
> Pokud to dobře chápu tak to napětí je závislé na proudech atd... A umí být u BC817 menší.
>

Ano, stejně jako umí být menší u toho klopného obvodu..  Nerozumím tomu co tu řešíme.. je to fundamentální omezení, které je u obou součástek stejné.  Pro tu aplikaci 0.5V nebo 0.8 V nebo i 1V prakticky nehraje roli..
Moje pointa byla v tom ušetřit počet součástek a tím pádem v důsledku i plochu na PCB.

kaklik, 2021-05-25:
Nakonec je návrh bez USB, takže toto issue je tím vyřešeno.

Closed 2021-05-25.

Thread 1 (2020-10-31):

Optimize SiK modem layout

kaklik, 2020-10-31:
Shrink the modem layout, but maintain conditions from [AN791](https://www.silabs.com/documents/public/application-notes/AN791.pdf)

kaklik, 2021-05-26:
Aktuální návrh nějak výrazně ignoruje doporučení z výše zmíněného application note.

Kde jejich doporučený layout vypadá takhle:

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

Pro náš případ na rychlý pohled vidím že minimálně:

1. LC matching network se vůbec nesnaží být blízko IC
2. Napájení TX části je až několik desítek milimetrů od IC.
3. Není moc izolován přeslech mezi RX a TX vylitou zemí mezi nimi.

A pak také jsou v návrhu některé základní obecné problémy, s layoutem RF cest.  Například není možné tahat jakoukoliv cestu paralelně na protější straně RF cesty.

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

Taktéž musí být maximálně minimalizovány přerušení protilehlé GND pod RF cestou.

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

Lze asi akceptovat přerušení GND pod součástkou, kde už tak jako tak dochází k nespojitosti pole.

kaklik, 2021-05-27:
Tohle se mi moc nelíbí:

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

Znamená to, mimo jiné, že výstupní RF konektory jsou prakticky úplně izolovány od země ve druhé vrstvě.
Druhý důsledek se kterým může být problém je to, že ty cesty takhle budou fungovat jako anténa a bude na nich vysílaný signál, který bude nějak ovlivňovat signál, který na těch ovládacích signálech má být jen on/off.

Jako řešení bych navrhoval nějak lépe proházet IO piny a jejich signály.
A cesty vést z levé strany, nikoliv z obou stran a pak udělat prostup pod L5 a L7, případně L3.
V případě že všechno nejde přeházet tak, aby to bylo jen zespodu, tak jeden signál může vést i pod C12 a L9.

Zkrátit by to chtělo i napájení. Protože napájení je z RF pohledu taky signál.

ChroustJan, 2021-06-04:
@kaklik  provedl jsem editaci. Prosím o kontrolu.

kaklik, 2021-06-04:
Super! Tohle řešení je mnohem lepší!

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

Potíž vidím v tom, že indikační LED D1, která indikuje přepínání RF RX/TX. Protože kdyby na modulu mělo být RF stínění, tak bude vypadat asi nějak takhle:

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

Tím pak nastane situace že na tuto LED nebude vidět.  Řešení by bylo buď LED přemístit k ostatním mimo, RF stínění, což je ale komplikováno přerušením GND od krystalu a místem.  Nebo LED uzpůsobit tak, aby svítala skrz PCB (To by ale pak bylo potřeba i u těch ostatních). Případně tuto LED úplně zrušit.

ChroustJan, 2021-06-07:
Navrhuji LED zrušit.

kaklik, 2021-06-07:
> Navrhuji LED zrušit.

OK..

kaklik, 2021-07-19:
Aktuálně je ještě potřeba:

- [ ] dořešit nepříjemnost s indikační LED pod stíněním.
- [ ] Připravit nějaké plochy, kde bude připojena stínící Cu páska
- [ ] Vyexportovat obrys do SVG, nebo DXF, aby se z toho dal v openscadu nakreslit 3D tisknutelný objekt.
- [ ] Zarovnat vias

ChroustJan, 2021-11-18:
Dodán chybějící popisek a vygenerování 3D modelu ve formátu .STEP. Zarovnání vias jsem nějaké udělal. Musí dodělat ten kdo to tu psal, aby dořešil ty zbylé co mu přišli nezarovnané.

kaklik, 2021-11-18:
> Dodán chybějící popisek a vygenerování 3D modelu ve formátu .STEP. Zarovnání vias jsem nějaké udělal. Musí dodělat ten kdo to tu psal, aby dořešil ty zbylé co mu přišli nezarovnané.

Ani jeden z těchto kroků ale neřeší výše zmíněné body.  Na dodání popisku antén je navíc jiné issue #12. STEP model nepomůže k tomu, aby šla v openscadu udělat kostra pod stínění..
Zarovnání vias asi můžu dořešit.

ChroustJan, 2021-11-18:
@kaklik takovéto SVG jsi si představoval? https://github.com/ThunderFly-aerospace/TFSIK01/blob/TFSIK01A/hw/sch_pcb/TFSIK01A-Edge_Cuts.svg

kaklik, 2021-11-18:
Porovnal jsem vias i potisky, tak aby se vzájemně nepřekrývaly.

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

Některé potisky jsem rovnou přesunul i tak, aby nebyly pod součástkami, nebo na ploše určené pro letování.

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

Zároveň jsem si ale všiml, že DRC u tohoto PCB nevypadá moc dobře:

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

Největší potíž jsou myslím chyby typu "Track has unconnected end", která obvykle je způsobená tím, že na cestě jsou položeny ještě další nikam nepřipojené segmenty.

kaklik, 2022-01-09:
Pro výrobu jsou problém následující body:

- Není jasné, kam zmizela šedivá vrstva, označující stíněnou RF část. S tím souvisí i záležitost, jak má vypadat ten separační výtisk, který bude dělat podporu stínící Cu pásce. Která v tomto řešení má nahrazovat stínící krabičku.
- Jestli při ztrátě vrstvy nedošlo ke ztrátě i dalších změn v návrhu
- Není také jasné, jak se vypořádat s DRC chybami, kterých je PCB nyní plné.

Closed 2025-08-14.

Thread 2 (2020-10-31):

Find a suitable RX LNA with differential output

kaklik, 2020-10-31:
To minimize the components count and increase the robustness a single-ended and differential output amplifier would be useful to connect the antenna RX/TX switch to Si1060 differential input.

Eg. Reducing this to single component:

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

The possible benefits are:

- Reducing component count on PCB -> reducing the size of the modem
- Make the balancing circuit independent of the frequency band. Therefore PCB board populated of the single BOM variant could operate on multiple ISM bands eg. 433 or 868 MHz or optionally 900 MHz for Region 2.
- Increase sensitivity by decrease the overall [noise figure](https://en.wikipedia.org/wiki/Noise_figure) of the whole transceiver.

kaklik, 2021-04-28:
According to [AN643](https://www.silabs.com/documents/public/application-notes/AN643.pdf).  The impedance matching to [Si4463](Si4463) internal LNA is not easily possible due to the frequency variability of LNA input parameters. Therefore a standard chip balun could not be used and a 4-element, matching circuit needs to be preserved.  FYI @ChroustJan

Closed 2021-04-28.

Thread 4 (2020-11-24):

Podpora Sik Multipoint firmware

kaklik, 2020-11-24:
Čip Si1060, neumožňuje použít [multipoint SiK](https://github.com/RFDesign/SiK/tree/SiK_Multipoint), protože má pouze 2Kb RAM paměti na rozdíl od jeho předchůdce Si1020.

Řešením zřejmě pouze je opatřit transceiver Si4463 jiným MCU.  Což je výhodné udělat i kvůli tomu, že Si1060 není kompatibilní s logikou  3.3V.

kaklik, 2021-11-18:
Cannot be solved with this hardware version.

Closed 2021-11-18.

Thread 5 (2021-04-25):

Autopilot connector

ChroustJan, 2021-04-25:
Pro připojení k autopilotu bude použit 6-pin JST-GH konektor. Kablík na propojení autopilota a modemu je 1:1

## Pinout konektoru na modemu
1. VCC
2. RX (autopilot-> modem)
3. TX (modem -> autopilot)
4. RTS
5. CTS
6. GND

## Pinout z polhedu autopilota.
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

ChroustJan, 2021-06-04:
Aplikováno na PCB

Closed 2021-06-04.

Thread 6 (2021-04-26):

Failed to exit bootloader after power voltage rise

kaklik, 2021-04-26:
U starších modemů založených na Si1000 byl pozorován jev, kdy při pomalém náběhu napájení se modem správně neinicializuje.
@roman-dvorak  od toho možná někde má i nějaké grafy.
Je potřeba si dát pozor, aby stejný problém nemohl vzniknout i v nové konstrukci.

ChroustJan, 2021-04-29:
@kaklik jak probíhá pomalý náběh napájení?

kaklik, 2021-04-29:
> @kaklik jak probíhá pomalý náběh napájení?

Některé měniče, například ten ve VESC, udělá pomalý náběh napětí při zapnutí.. Trochu doufám, že k tomu má @roman-dvorak  nějaký snímek z osciloskopu, protože já nevím kde je.

ChroustJan, 2021-04-29:
Tohle nevím, jak moc dobře řešit. Jedině, že by jsme hlídali úroveň napětí a dokud nebude větší tak to nezapneme. Ten náš stabilizátor má EN pin.

kaklik, 2021-04-29:
> Tohle nevím, jak moc dobře řešit. Jedině, že by jsme hlídali úroveň napětí a dokud nebude větší tak to nezapneme. Ten náš stabilizátor má EN pin.

ano jsou v zásadě dvě možnosti jak to udělat. Buď povolovat napájení ze stabilizátoru, po tom co je stabilní a nebo držet reset dokud se neustabilizuje napájení a pak ho pustit.
Některý měniče mají právě z tohoto důvodu PG pin, který jde použít na uvolnění resetu po tom, co se stabilizuje napájení.

roman-dvorak, 2021-04-29:
> > @kaklik jak probíhá pomalý náběh napájení?
>
> Některé měniče, například ten ve VESC, udělá pomalý náběh napětí při zapnutí.. Trochu doufám, že k tomu má @roman-dvorak nějaký snímek z osciloskopu, protože já nevím kde je.

Tak je to přesně naopak. Viz tento zápis:
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

kaklik, 2021-04-29:
Zajímavé. Možná tak není problém s rychlostí náběhu, ale spíše s tím zákmitem na začátku.   V [datasheetu](https://www.silabs.com/documents/public/data-sheets/Si106x-8x.pdf) jsou následující podmínky, kdy vznikne reset:

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

Aby to spolehlivě fungovalo, tak je zřejmě potřeba se všem vyhnout.

kaklik, 2022-11-06:
Tenhle problém souvisí s náběhem napájení zřejmě jen okrajově. Reálnou příčinou je že se uzeměním CTS aktivuje bootloader.  Si10XX ale nemá dostatečně silný pull-up, který by zajistil log 1 při náběhu napájení.  Místo toho, má naopak logiku, která při log nule na vstupu pull-up vypne. V autopilotovi navíc je obousměrný translator, který se podle logických stavů snaží odhadnout směr komunikace.  Kombinace těchto dvou řešení způsobí, že se při spouštění zařízení prochází nedefinovanými stavy. Výsledkem tak je, že spuštění nebo zaseknutí v bootloaderu závisí na rychlosti náběhu napájení.

Korektním řešením by možná bylo přidání externího pull-upu na signál CTS.

Closed 2025-09-08.

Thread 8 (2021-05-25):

Last time buy of LNA IC

kaklik, 2021-05-25:
The selected chip [SPF5189Z](https://www.qorvo.com/products/p/SPF5189Z#parameters) has End of Life announced on March 8, 2021.
The manufacturer proposes the use of [QPL9547](https://www.qorvo.com/products/p/QPL9547#parameters), which has a similar characteristic on the first look.

The noticeable feature is Shutdown input, which allows direct control of LNA from MCU IO pin. Therefore the current LNA control logic could be significantly reduced:

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

To the following circuit

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

The unknown value is a value of resistor R4, which sets the bias point. Datasheets do not explain the possible range of values. But it is suspected, that current thought this resistor should be in the range from 65mA to 100mA.

Resistors R3, R2, and R1 should be omitted.

----

@ChroustJan  Dovedeš osadit i tu novou verzi?

ChroustJan, 2021-05-27:
Ano. @kaklik takže takto má vypadat nové výsledné zapojení?
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

R4 zvoleno 3k32 po vzoru Evaluation Board – QPL9547EVB-01

kaklik, 2021-05-27:
Na tom GPIO2 bych zachoval tu LED D5, co tam vlastně byla.   Dal bych k ní popisek RF RX, pokud bude z napájení do pinu, tak bude svítit, když je zapnuný LNA (ten je zapnutý v nule).

Jinak je to ok. .. Ta  hodnota toho R4 se asi bohužel bude muset experimentálně vyzkoušet, na to řešení teď nemám.

ChroustJan, 2021-06-04:
Aplikován QPL9547 a přidána LED.

Closed 2021-06-04.

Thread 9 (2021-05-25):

Možnost zasouvání PCB do drážek držáku

kaklik, 2021-05-25:
Při plánování rozměrů PCB jsme předpokládali, že plošný spoj půjde zasouvat do drážek ve kterých se pak pojistí šrouby zašroubovanými v místech výřezů do desky.
Předpokládá to ovšem, že drážka může mít šířku alespoň srovnatelnou s hloubkou zubu pro šroub na boku PCB. Tomu ale brání aktuální pozice některých součástek na PCB.

Zejména krystalu Y2, dobře na tom ale nejsou ani LED D2 a D3.

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

U krystalu je tato záležitost ale obvzláště zřejmá, neboť je krystal navíc i výrazně daleko od samotného IC.
Podobně je na tom kondenzátor C1 na protilehlé straně.

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

Domnívám se, že umístění součástek by mělo být takové, aby pro uchycení PCB byla k dispozici alespoň šířka odpovídající hloubce půlkulatých výřezů na stranách PCB.

ChroustJan, 2021-05-26:
Ale ten půlkulatý výřez má 1,5mm.

ChroustJan, 2021-06-04:
Je splněn požadavek na minimální mezeru 1mm od okraje.

kaklik, 2021-06-04:
> Je splněn požadavek na minimální mezeru 1mm od okraje.

No já nevim, jestli je jako dobrý tohle prostě takhle zazdít, s tím že je "splněno", něco co jsme jen odhadli.  Když to zároveň není nikde namontované..  Myslím že nějaká krabička se bude dělat o dost hůře v případě, že tam bude jen tak tak 1mm.

Closed 2021-06-04.

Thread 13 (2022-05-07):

LED indicating antenna selection

roman-dvorak, 2022-05-07:
Bylo by docela fajn přidat na PCB LEDku, která by signalizovala použitou anténu. Z hlediska SW by to mělo jít vyřešit: https://github.com/ThunderFly-aerospace/SiK/issues/8

Znamenalo by to tedy přidat LEDku na pin P1.6

kaklik, 2022-09-13:
Vypadá to, že požadovaná LED je na PCB přidaná, pouze není vyřena podpora uvnitř FW a dotyčná LED po zapnutí napájení stále svítí.

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

Closed 2022-09-13.

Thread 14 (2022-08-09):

Missing power led

roman-dvorak, 2022-08-09:
V návrhu chybí LEDka indikující přítomnost napájení

kaklik, 2022-11-07:
Vzhledem k tomu že tam jsou tři jiné LED, které by za normálního stavu měly být aktivní, tak to možná není významný problém. Tím by šlo power led přidat jen pokud na stávajícím PCB bude místo.

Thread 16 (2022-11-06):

MCX connector mounting strength

kaklik, 2022-11-06:
MCX konektory jsou nyní zaletovány do PCB jen z jedné strany. To povede k tomu, že se z PCB snadno vylomí. Lepší by bylo v následující verzi umožnit přiletování z obou stran. Nebo nechat pokovit hranu PCB na kterou se letují.

kaklik, 2025-08-14:
Vyřešeno přidáním možnosti letovat konektory z obou stran.

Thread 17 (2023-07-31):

Table in silksceen to mark HW frequency band

kaklik, 2023-07-31:
There should be a table in silkscreen to mark frequency bands matching the populated components on the PCB. The possible cases supported in the firmware are currently:

- 433 MHz
- 868 MHz
- 915 MHz

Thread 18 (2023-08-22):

Optimize variants fot common ISM frequency bands 433 MHz, 868 MHz, 915 MHz.

kaklik, 2023-08-22:
Aktuálně je RX strana optimalizována pro pásma 434 MHz a 868 MHz.

TX strana je naladěna pouze na 460 MHz. V [AN648 Tab. 5.](https://www.silabs.com/content/usergenerated/asi/cloud/attachments/siliconlabs/en/community/wireless/bluetooth/forum/jcr:content/content/primary/qna/tune_an_rf_pico_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) chybí hodnoty součástek pro 433 MHz.

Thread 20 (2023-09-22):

Fine tune output power by Voltage-Limiting Resistor

kaklik, 2023-09-22:
Na 3V3 TX by se hodilo přidat rezistor v pouzdru 0805, kterým by bylo možné precizněji nastavit maximální vysílací výkon.

Closed 2025-09-08.

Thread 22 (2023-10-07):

Antenna connectors clearance

kaklik, 2023-10-07:
Při sestavování větší série TFSIK modemů se ukázalo, že některé MCX konektory jsou zapadlé pod úroveň hrany PCB. Bylo by myslím vhodné návrh upravit tak, aby konektory vycházely spíše s kladnou tolerancí. To znamená zároveň nebo s přesahem na hraně PCB.
Takové řešení by umožnilo snížit nároky na konstrukci krabičky modemu.

Closed 2025-08-14.

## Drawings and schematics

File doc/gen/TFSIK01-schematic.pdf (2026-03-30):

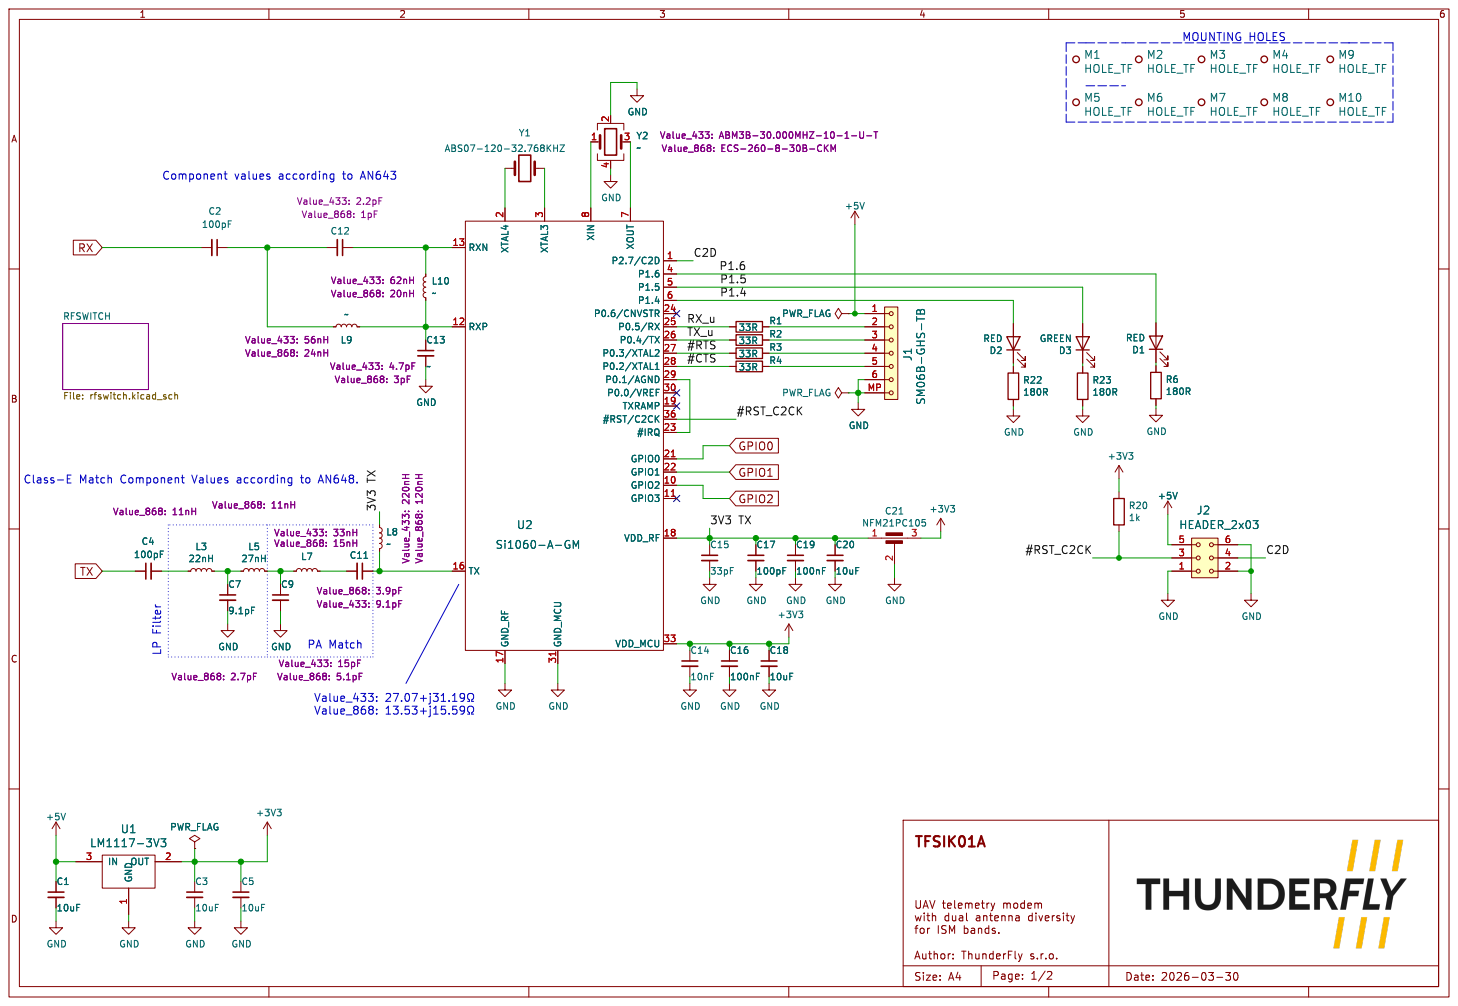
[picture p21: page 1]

7 P2.7/C2D 1 P1.6 4 P1.5 5 P1.4 6 P0.6/CNVSTR 24 P0.5/RX 25 P0.4/TX 26 P0.3/XTAL2 27 P0.2/XTAL1 28 P0.1/AGND 29 P0.0/VREF 30 TXRAMP 19

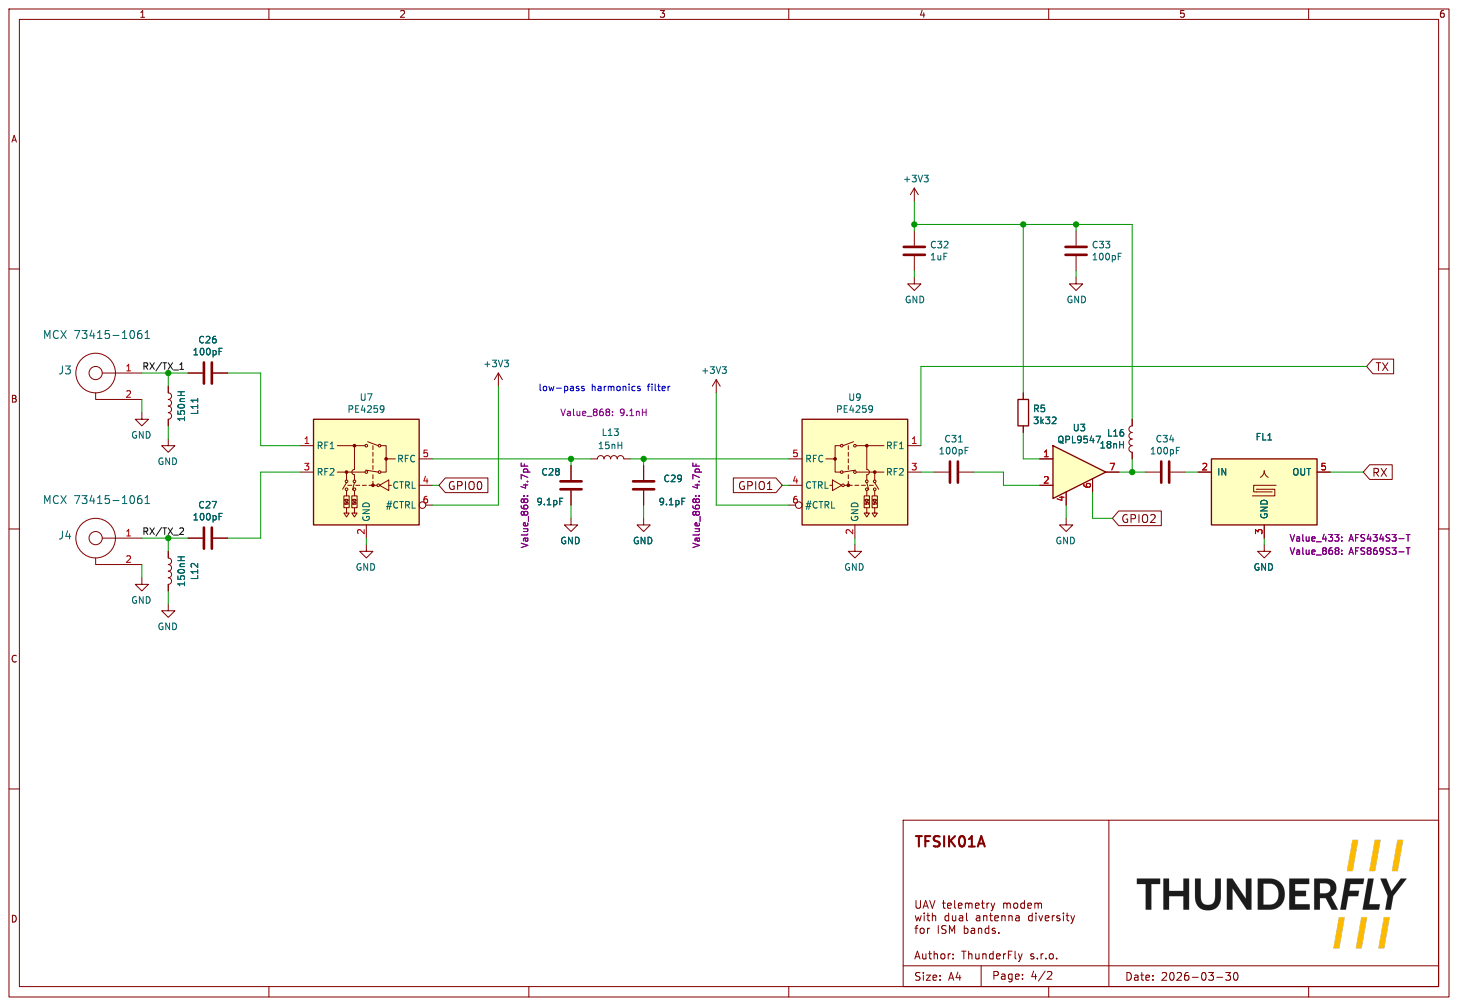
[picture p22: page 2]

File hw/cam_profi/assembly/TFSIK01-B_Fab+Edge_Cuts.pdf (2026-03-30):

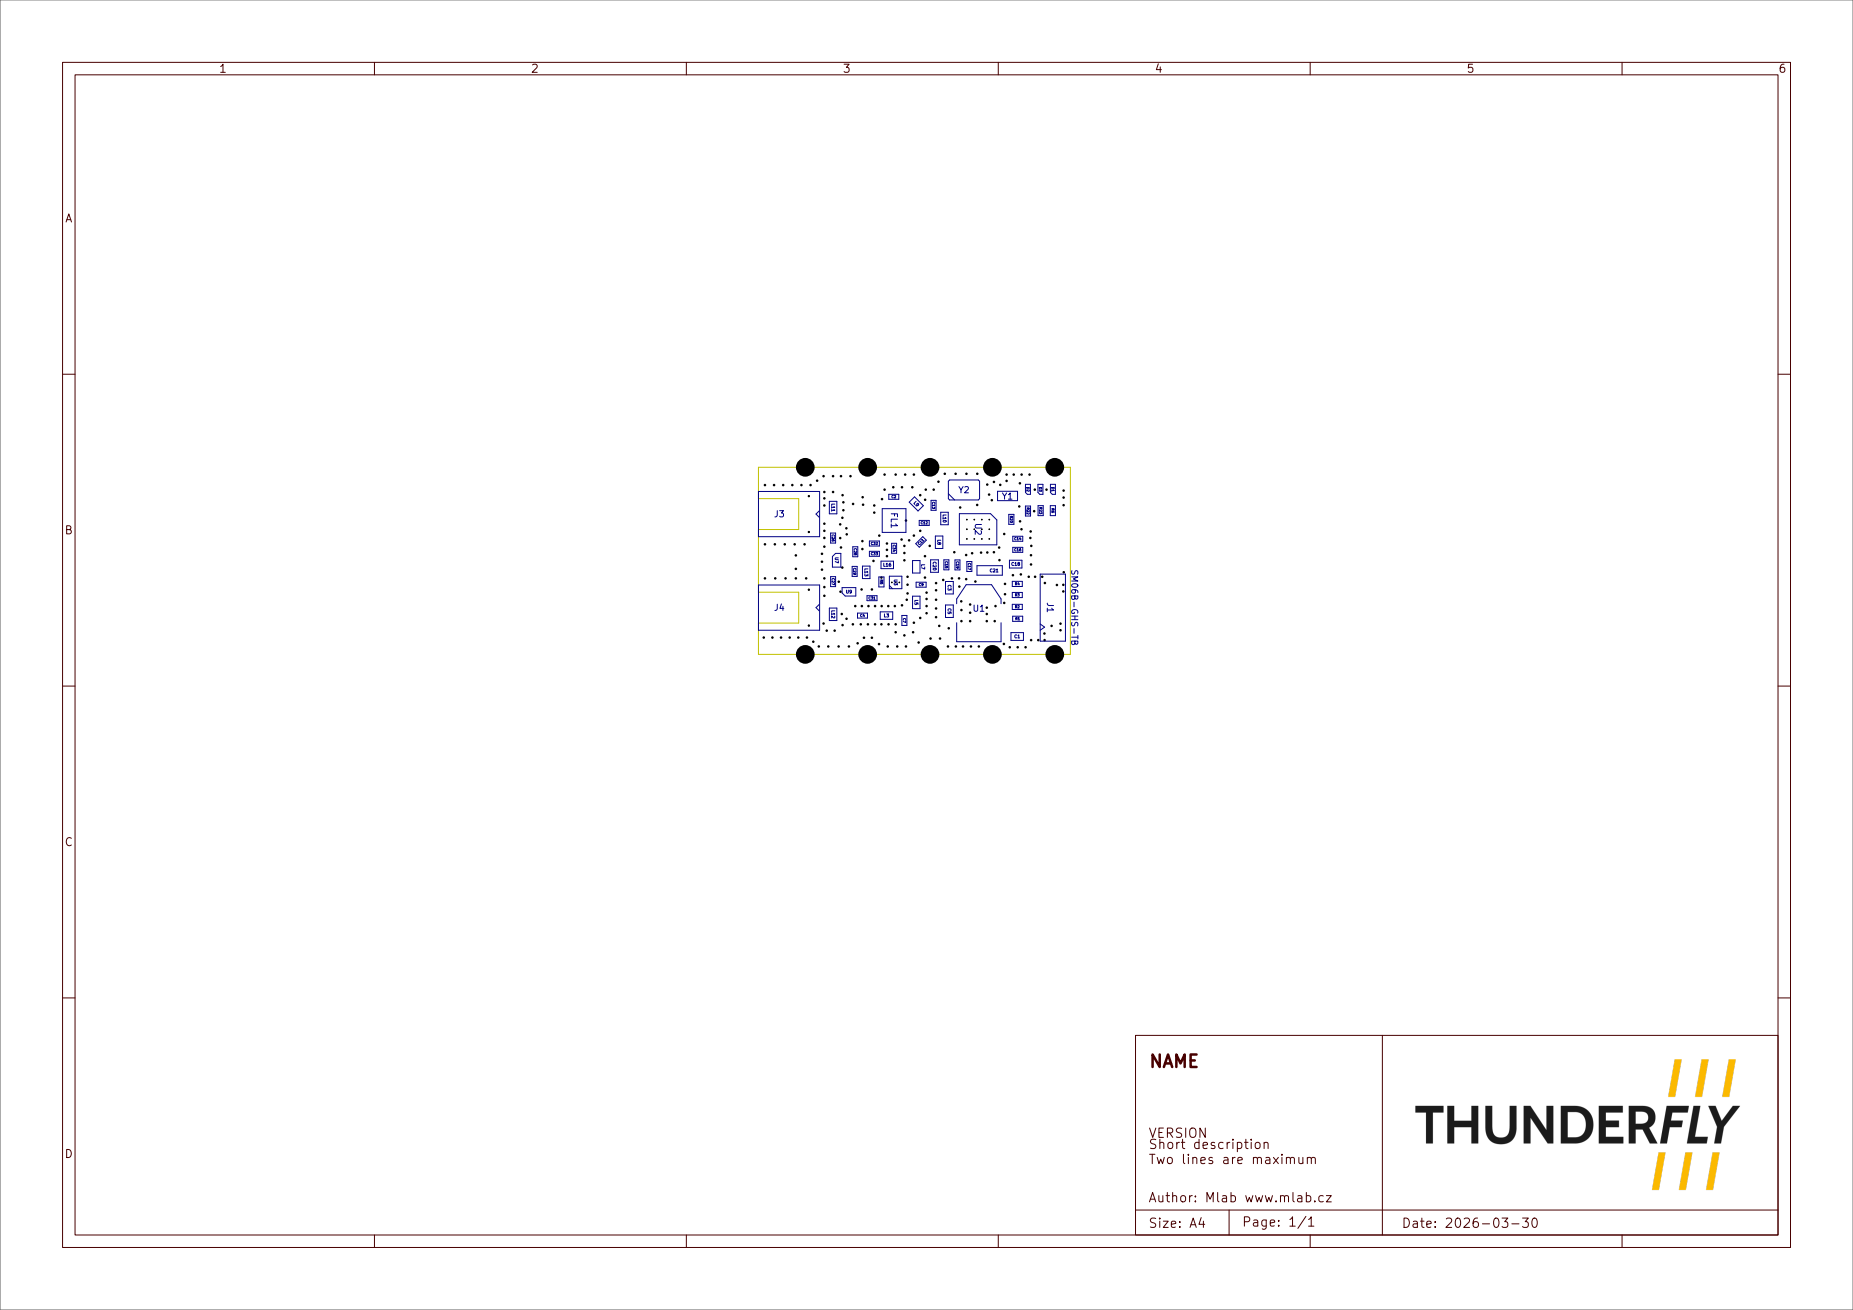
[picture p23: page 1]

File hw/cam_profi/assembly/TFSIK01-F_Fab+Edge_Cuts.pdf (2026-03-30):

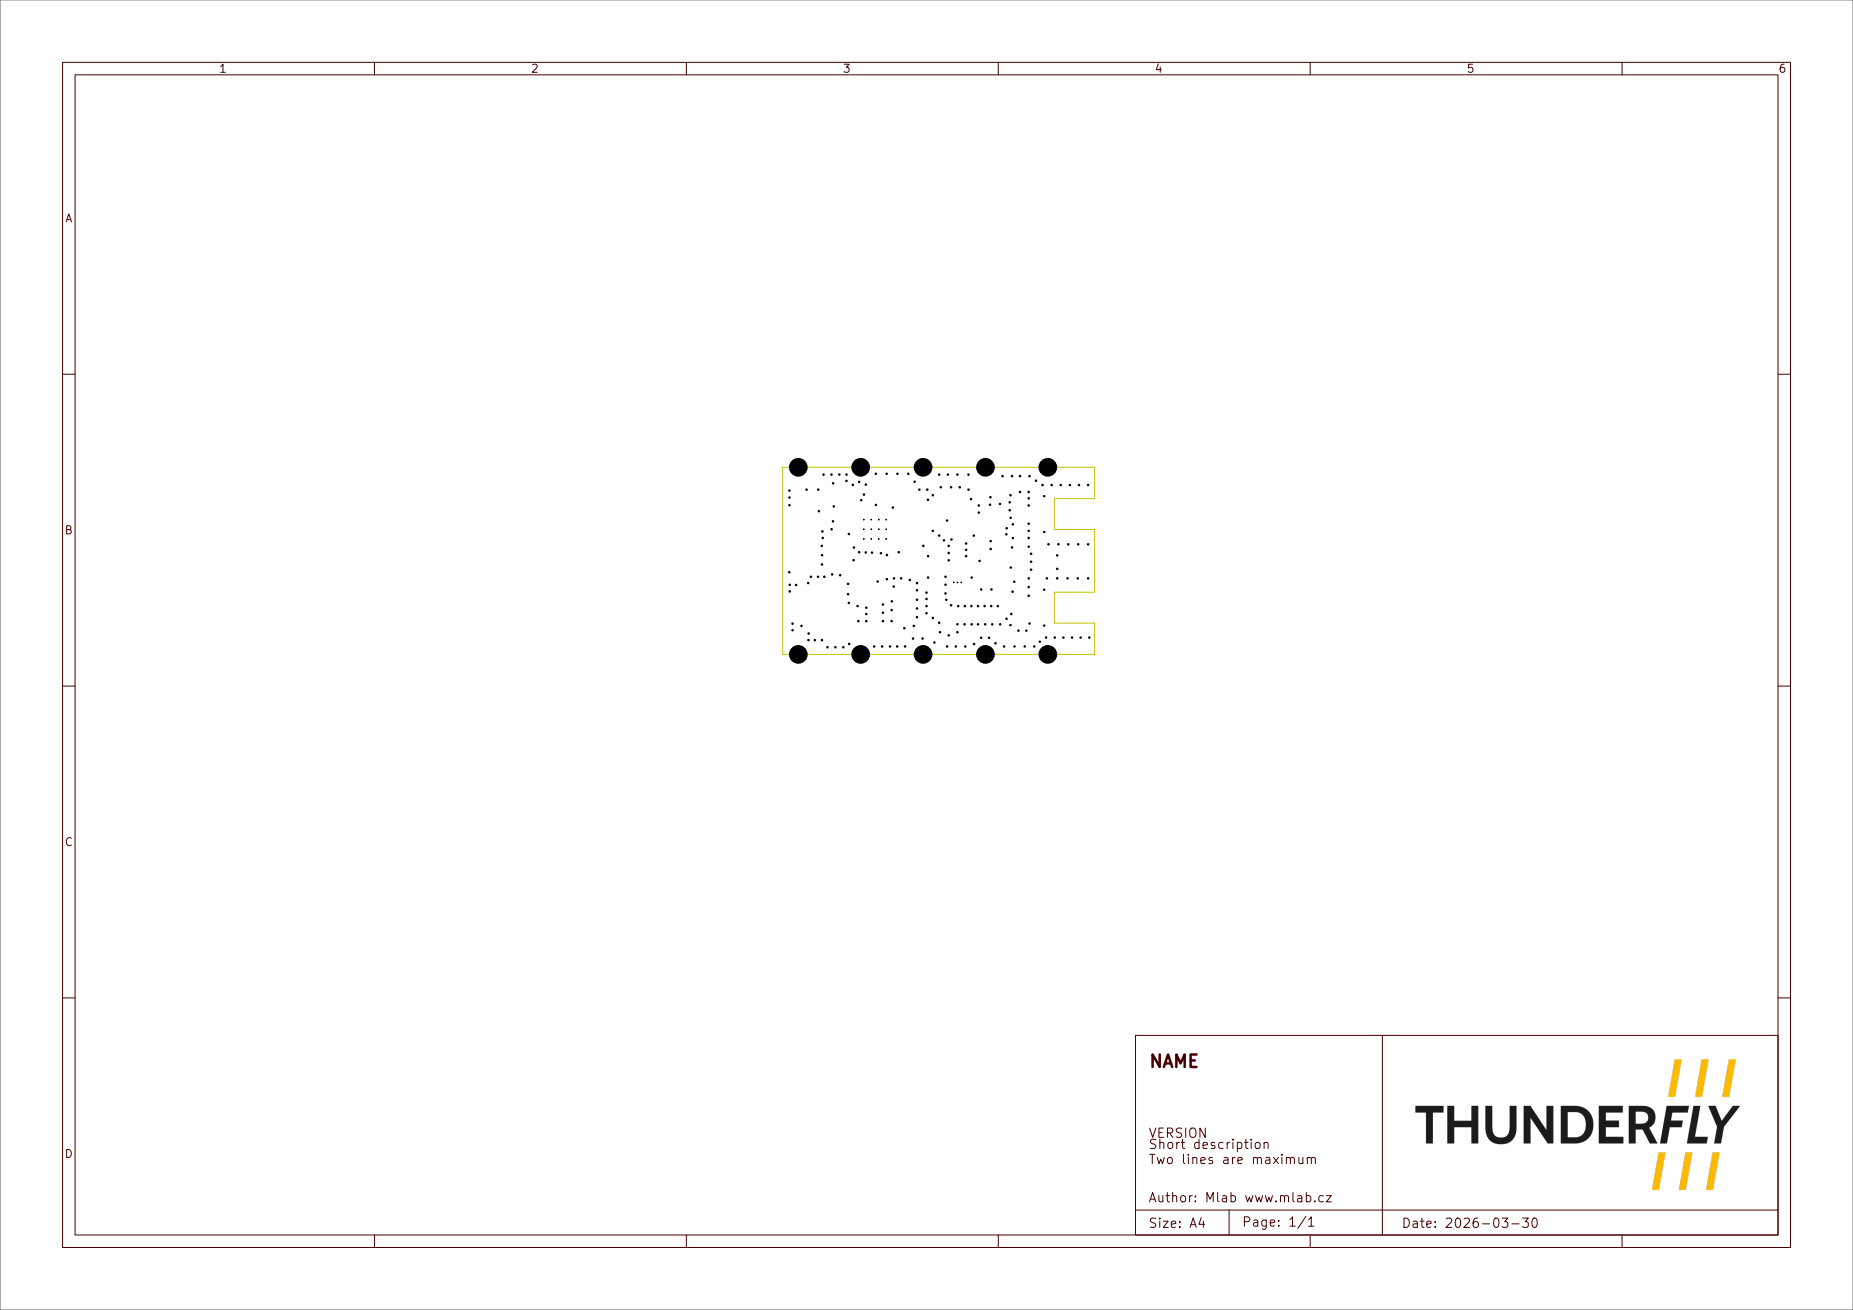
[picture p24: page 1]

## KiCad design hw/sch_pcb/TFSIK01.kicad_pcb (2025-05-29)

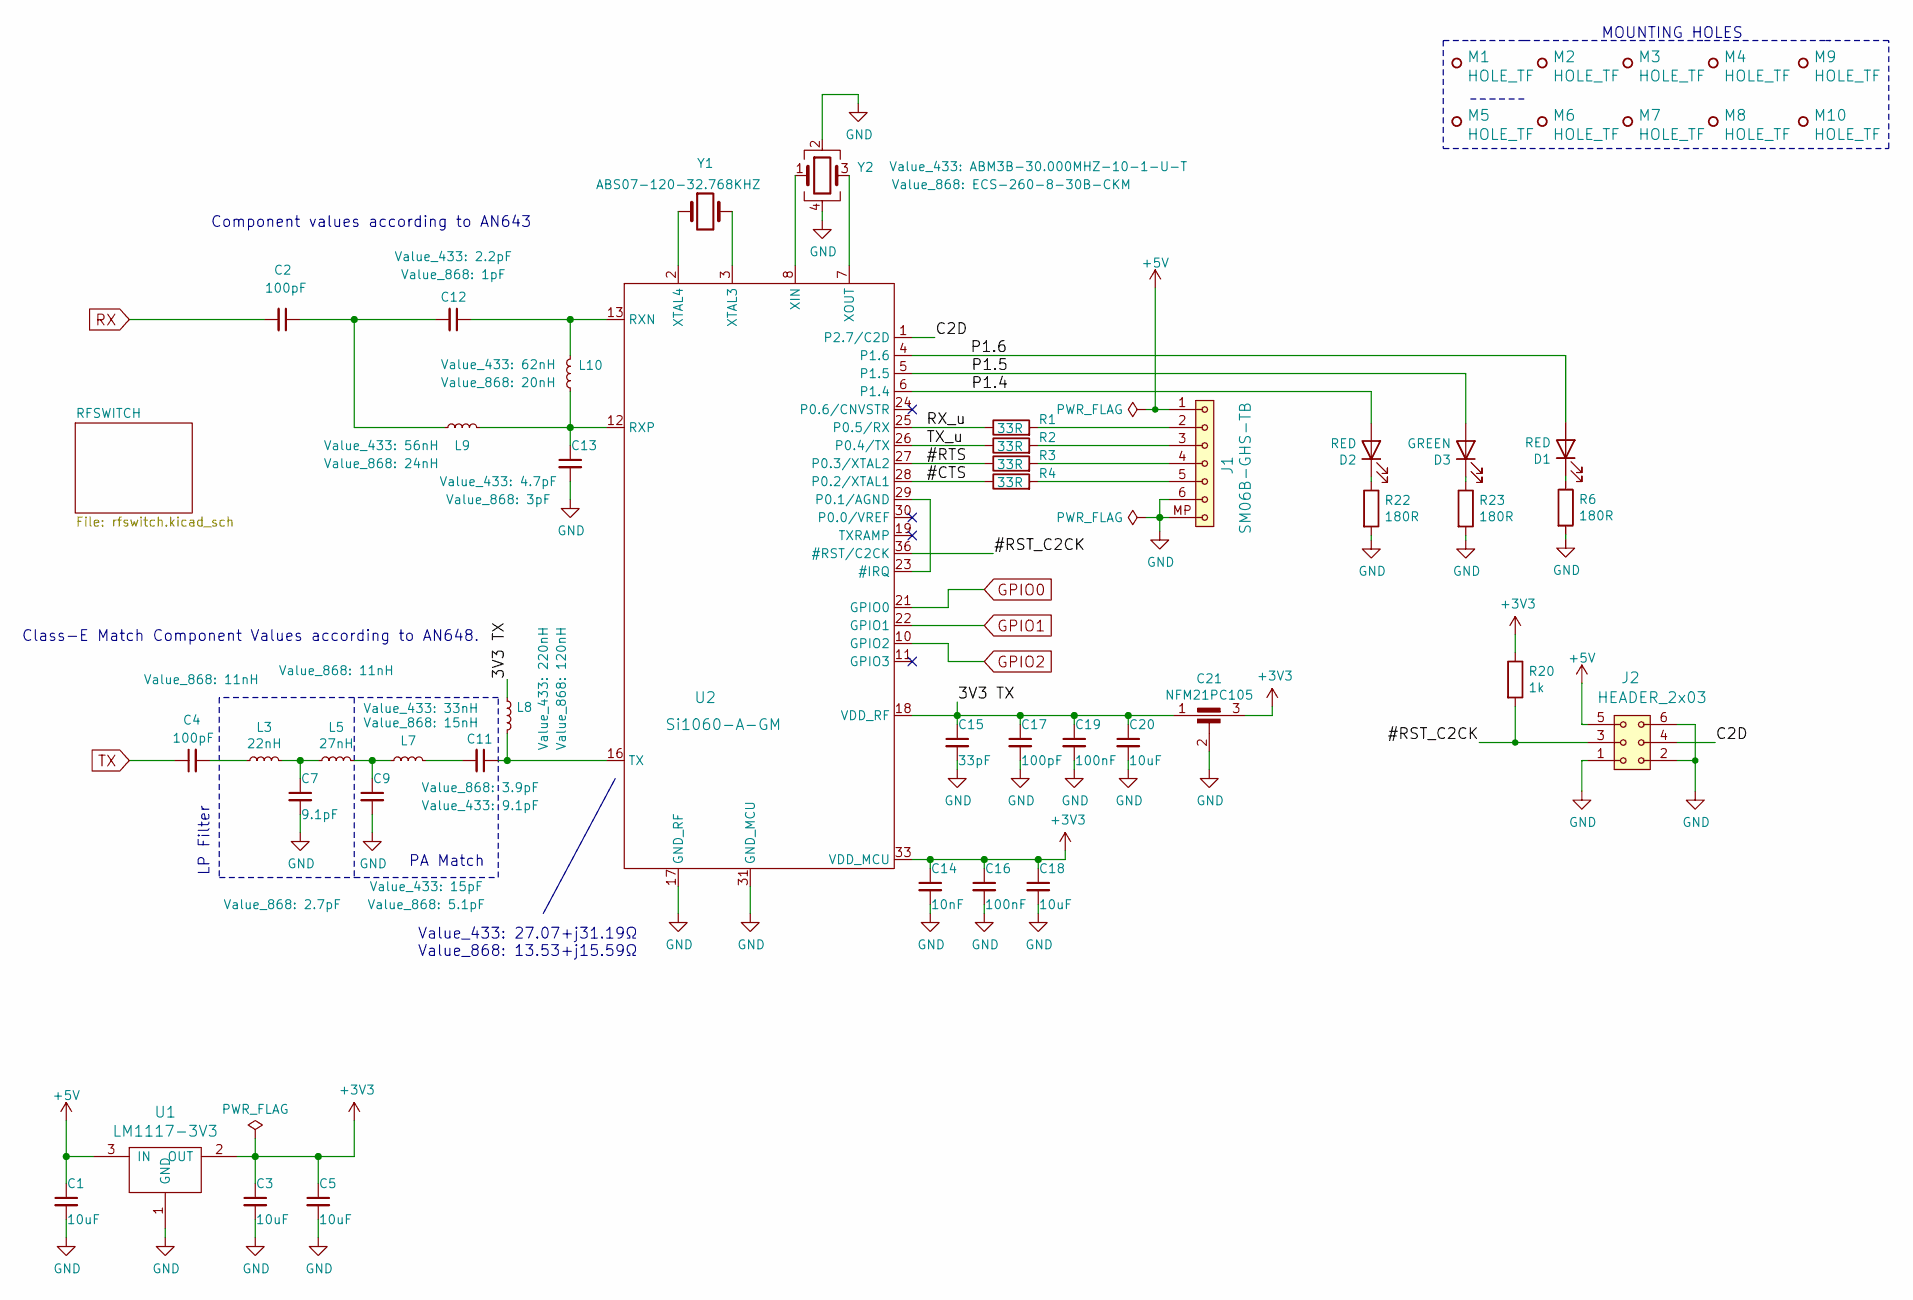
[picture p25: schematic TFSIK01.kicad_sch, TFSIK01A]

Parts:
C1, C3, C5, C18, C20: 10uF; C_0805_2012Metric
C2, C4, C17: 100pF; C_0603_1608Metric
C7: 9.1pF; C_0603_1608Metric
C9: 13pF; C_0603_1608Metric
C11: 8,2pF; C_0603_1608Metric
C12, C13: C_0603_1608Metric
C14: 10nF; C_0603_1608Metric
C15: 33pF; C_0603_1608Metric
C16, C19: 100nF; C_0603_1608Metric
C21: NFM21PC105; FIR_0805
D1, D2: RED; LED_0603_1608Metric_Pad1.05x0.95mm_HandSolder
D3: GREEN; LED_0603_1608Metric_Pad1.05x0.95mm_HandSolder
J1: SM06B-GHS-TB; JST_GH_SM06B-GHS-TB_1x06-1MP_P1.25mm_Horizontal
J2: HEADER_2x03; SMD_2x03
L3: 22nH; L_0805_2012Metric_Pad1.15x1.40mm_HandSolder
L5: 27nH; L_0805_2012Metric_Pad1.15x1.40mm_HandSolder
L7: 30nH; L_0805_2012Metric_Pad1.15x1.40mm_HandSolder
L8, L9, L10: L_0805_2012Metric_Pad1.15x1.40mm_HandSolder
M1, M2, M3, M4, M5, M6, M7, M8, M9, M10: HOLE_TF; dira_3mm
R1, R2, R3, R4: 33R; R_0603_1608Metric
R6, R22, R23: 180R; R_0603_1608Metric
R20: 1k; R_0603_1608Metric
U1: LM1117-3V3; SOT-223
U2: Si1060-A-GM; QFN-36-1EP_5x6mm_P0.5mm_EP3.6x4.1mm_ThermalVias
Y1: ABS07-120-32.768KHZ; ABS07
Y2: Crystal_SMD_Abracon_ABM3B-4Pin_5.0x3.2mm

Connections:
+3V3: C3.1, C5.1, C14.1, C16.1, C18.1, C21.3, R20.1, U1.2 (OUT), U1.4 (OUT), U2.33 (VDD_MCU); also elsewhere on the board
+5V: C1.1, J1.1, J2.5, U1.3 (IN)
/3V3 TX: C15.1, C17.1, C19.1, C20.1, C21.1, L8.1, U2.18 (VDD_RF), U2.20 (VDD_RF)
/#CTS: R4.1, U2.28 (P0.2/XTAL1)
/#RST_C2CK: J2.3, R20.2, U2.36 (#RST/C2CK)
/#RTS: R3.1, U2.27 (P0.3/XTAL2)
/C2D: J2.4, U2.1 (P2.7/C2D)
/P1.4: D2.2 (A), U2.6 (P1.4)
/P1.5: D3.2 (A), U2.5 (P1.5)
/P1.6: D1.2 (A), U2.4 (P1.6)
/RX_u: R1.1, U2.25 (P0.5/RX)
/TX_u: R2.1, U2.26 (P0.4/TX)
GND: C1.2, C3.2, C5.2, C7.2, C9.2, C13.2, C14.2, C15.2, C16.2, C17.2, C18.2, C19.2, C20.2, C21.2, J1.6, J1.MP, J2.1, J2.2, J2.6, R6.2, R22.2, R23.2, U1.1 (GND), U2.9 (GND_RF), U2.14 (GND_RF), U2.15 (GND_RF), U2.17 (GND_RF), U2.31 (GND_MCU), U2.37 (GND_RF), Y2.2, Y2.4; also elsewhere on the board
GPIO0: U2.21 (GPIO0); also elsewhere on the board
GPIO1: U2.22 (GPIO1); also elsewhere on the board
GPIO2: U2.10 (GPIO2); also elsewhere on the board
unnamed: C4.2, L3.1
unnamed: C7.1, L3.2, L5.1
unnamed: C9.1, L5.2, L7.1
unnamed: C11.2, L7.2
unnamed: C2.1, C12.2, L9.1
unnamed: D1.1 (K), R6.1
unnamed: D2.1 (K), R22.1
unnamed: D3.1 (K), R23.1
unnamed: J1.2, R1.2
unnamed: J1.3, R2.2
unnamed: J1.4, R3.2
unnamed: J1.5, R4.2
unnamed: U2.23 (#IRQ), U2.29 (P0.1/AGND)
unnamed: C12.1, L10.2, U2.13 (RXN)
unnamed: C13.1, L9.2, L10.1, U2.12 (RXP)
unnamed: C11.1, L8.2, U2.16 (TX)
unnamed: U2.8 (XIN), Y2.1
unnamed: U2.7 (XOUT), Y2.3
unnamed: U2.3 (XTAL3), Y1.2
unnamed: U2.2 (XTAL4), Y1.1
RX: C2.2; also elsewhere on the board
TX: C4.1; also elsewhere on the board

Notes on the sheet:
MOUNTING HOLES
Value_433: 27.07+j31.19Ω Value_868: 13.53+j15.59Ω
PA Match
Class-E Match Component Values according to AN648.
Component values according to AN643
LP Filter

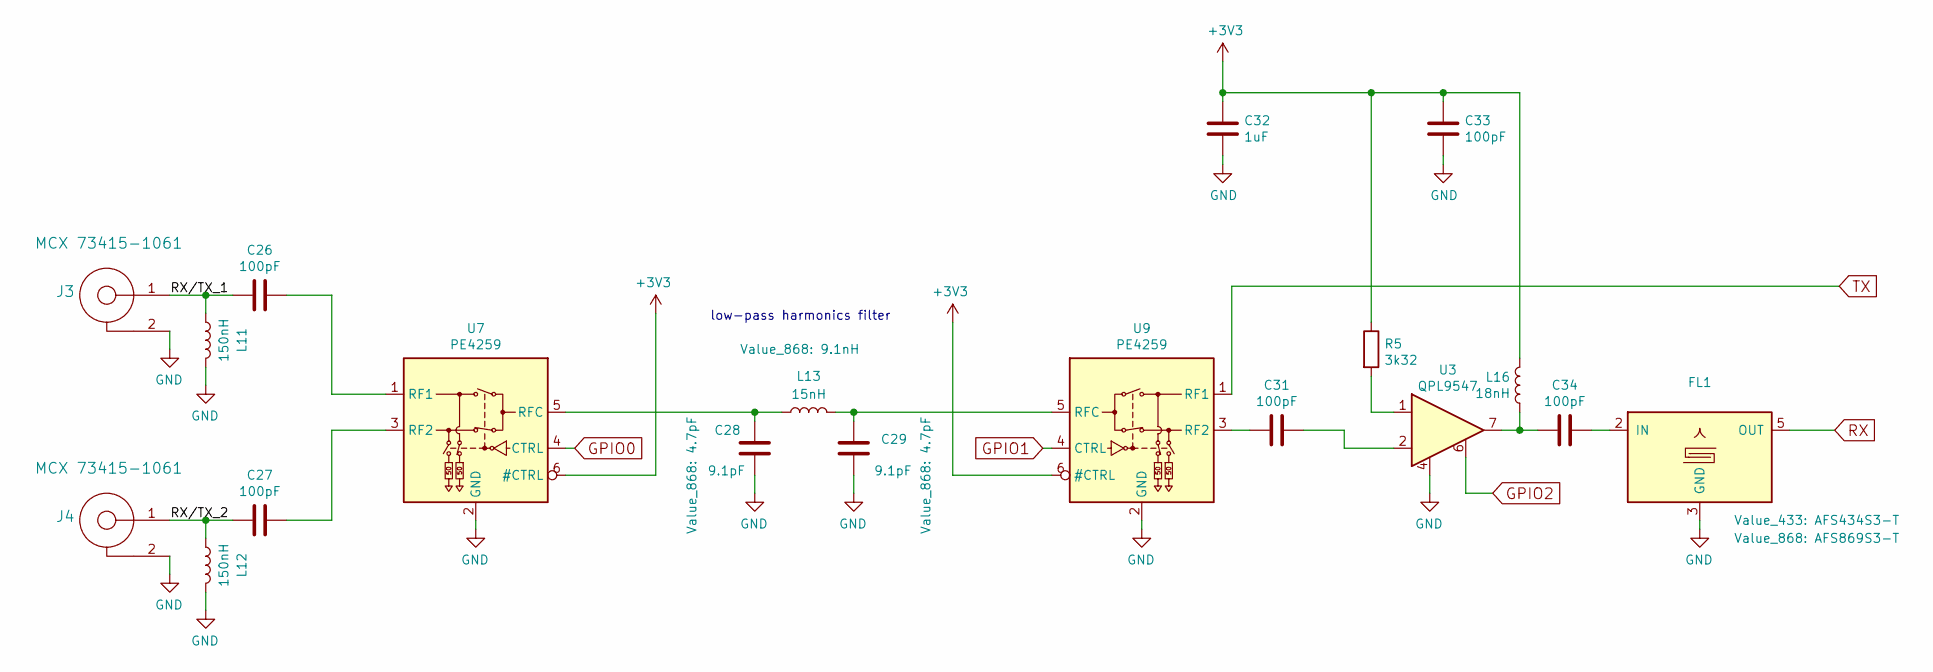
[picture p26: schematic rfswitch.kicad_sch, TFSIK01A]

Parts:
C26, C27, C31, C33, C34: 100pF; C_0603_1608Metric
C28, C29: 9.1pF; C_0603_1608Metric
C32: 1uF; C_0603_1608Metric
FL1: ABRACON_AFS
J3, J4: MCX 73415-1061; MCX_Molex_73415-1061
L11, L12: 150nH; L_0805_2012Metric_Pad1.15x1.40mm_HandSolder
L13: 15nH; L_0805_2012Metric_Pad1.15x1.40mm_HandSolder
L16: 18nH; L_0805_2012Metric_Pad1.15x1.40mm_HandSolder
R5: 3k32; R_0603_1608Metric
U3: QPL9547; SON50P200X200X95-9N-D
U7, U9: PE4259; SOT-363_SC-70-6

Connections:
+3V3: C32.1, C33.1, L16.1, R5.1, U7.6 (#CTRL), U9.6 (#CTRL); also elsewhere on the board
/RFSWITCH/RX/TX_1: C26.2, J3.1, L11.2
/RFSWITCH/RX/TX_2: C27.2, J4.1, L12.2
GND: C28.2, C29.2, C32.2, C33.2, FL1.1 (GND), FL1.3 (GND), FL1.4 (GND), FL1.6 (GND), J3.2, J4.2, L11.1, L12.1, U3.3, U3.4, U3.5, U3.8, U3.9, U7.2 (GND), U9.2 (GND); also elsewhere on the board
GPIO0: U7.4 (CTRL); also elsewhere on the board
GPIO1: U9.4 (CTRL); also elsewhere on the board
GPIO2: U3.6; also elsewhere on the board
unnamed: C31.1, U3.2
unnamed: C34.2, L16.2, U3.7
unnamed: C34.1, FL1.2 (IN)
unnamed: R5.2, U3.1
unnamed: C26.1, U7.1 (RF1)
unnamed: C27.1, U7.3 (RF2)
unnamed: C28.1, L13.2, U7.5 (RFC)
unnamed: C31.2, U9.3 (RF2)
unnamed: C29.1, L13.1, U9.5 (RFC)
RX: FL1.5 (OUT); also elsewhere on the board
TX: U9.1 (RF1); also elsewhere on the board

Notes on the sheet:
low-pass harmonics filter

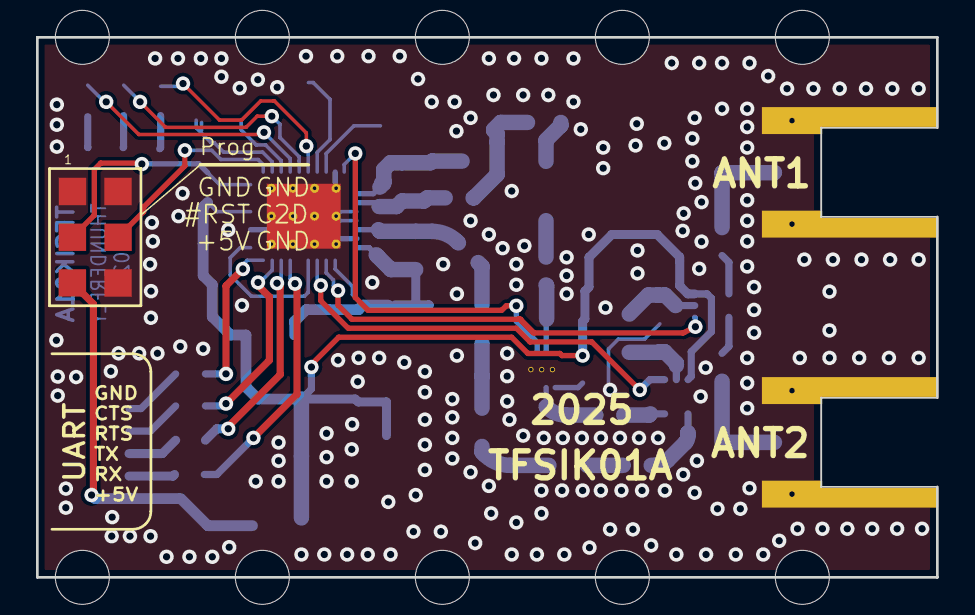
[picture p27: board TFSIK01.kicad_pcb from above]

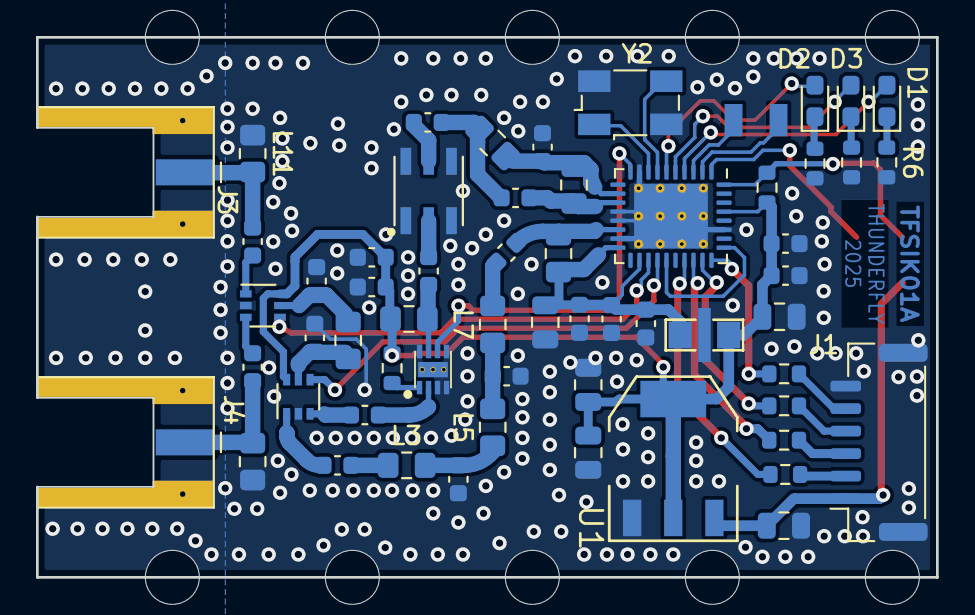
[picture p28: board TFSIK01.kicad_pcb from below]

Board: 2 copper layers, 50.0 x 30.0 mm, 70 parts (59 on the bottom side), 49 nets.

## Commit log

2021-05-13 Edit schema
    [TFSIK01A.kicad_sch, USB_UART.kicad_sch, rfswitch.kicad_sch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]
2021-05-19 Resolve #7 RX and TX matching network.
    [TFSIK01A.kicad_sch, rfswitch.kicad_sch]
2021-05-19 Repair title block.
    [TFSIK01A.kicad_sch]
2021-05-24 Edit PCB
    [TFSIK01A.kicad_pcb, TFSIK01A.kicad_sch]
2021-05-25 Tune values in schematics.
    [TFSIK01A.kicad_sch, rfswitch.kicad_sch]
2021-05-27 Edit SCH and PCB
    [TFSIK01A.kicad_pcb, TFSIK01A.kicad_sch, rfswitch.kicad_sch]
2021-05-27 Improve layout. minor movement of RF components.
    [TFSIK01A.kicad_pcb, TFSIK01A.kicad_sch]
2021-06-04 #1 edit PCB
    [TFSIK01A.kicad_pcb, TFSIK01A.kicad_sch]
2021-06-04 Add draft layout of RF shield.
    [TFSIK01A.kicad_pcb]
2021-06-07 A new RF shilding layout.
    [TFSIK01A.kicad_pcb]
2021-06-09 Updating the schematics.
2021-07-19 Improve layout #1 * Position of voltage regulator capacitors were shifted to make room for shielding box * RF paths filleted * Fix wrong solder mask in RF filter GND vias.
    [TFSIK01A.kicad_pcb]
2021-08-17 Edit BOM
    [TFSIK01A.csv, TFSIK01A.kicad_sch, rfswitch.kicad_sch]
2021-11-18 Edit labels and generate 3D model .STEP
    [TFSIK01A.kicad_pcb, TFSIK01A.kicad_sch, TFSIK01A.step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]
2021-11-18 Layout and silkscreen improvements. #1 Schematics page regenerated with correct title block.
    [TFSIK01A.kicad_pcb, TFSIK01A.kicad_sch, rfswitch.kicad_sch]
2022-05-05 Edit PCB. DRC. Change of housings L0805
    [TFSIK01A.kicad_pcb, TFSIK01A.kicad_sch, rfswitch.kicad_sch]
2022-05-05 Edit kicad_outputs.yml
    [TFSIK01A.csv, TFSIK01A.step]
2022-05-05 Update actions products
    [TFSIK01A-B_Courtyard.dxf, TFSIK01A-B_Cu.dxf, TFSIK01A-B_Fab.dxf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]
2022-05-05 Cleaning folders
    [ISM01A-B.Cu.gbr, ISM01A-B.Mask.gbr, ISM01A-Edge.Cuts.gbr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]
2022-05-11 Edit #13
    [TFSIK01A.kicad_pcb, TFSIK01A.kicad_sch]
2022-05-12 uprava silkscreenu
    [TFSIK01A.kicad_pcb]
2022-05-25 Priprava pro osazovani
    [TFSIK01A.kicad_pcb, TFSIK01A.kicad_sch, rfswitch.kicad_sch]
2022-08-01 Minor schematics clarity improvements
    [TFSIK01A.kicad_sch, rfswitch.kicad_sch]
2022-08-01 Cleanup unused schematic files. Add UST_ID to variant of SAW filters.
    [TFSIK01A.kicad_sch, USB_UART.kicad_sch, rfswitch.kicad_sch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]
2022-09-12 FIX wrong net name of GPIO3.
    [TFSIK01A.kicad_sch, rfswitch.kicad_sch]
2023-07-20 Edit UST_ID
    [TFSIK01A.kicad_sch, rfswitch.kicad_sch]
2023-07-30 Improve silkscreen D2 anotation.
    [TFSIK01A.kicad_pcb]
2023-07-31 Cleanup schematics sove some off grid placed nets and components.
    [TFSIK01.kicad_pcb, TFSIK01.kicad_sch, rfswitch.kicad_sch]
2023-08-01 Correct frequency option note.
    [TFSIK01.kicad_sch]
2023-08-01 Make singe 433MHz variant schematics.
    [TFSIK01.kicad_sch, rfswitch.kicad_sch]
2023-08-01 Mark variant to both 868 MHz and 433 MHz ISM bands.
    [TFSIK01.kicad_sch]
2023-08-02 initial commit of shielding support and bottom part of box
    [rf_shield.3mf, rf_shield.scad, rf_shield.stl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]
2023-08-03 TFSIK box, 3D design
    [tf_box.3mf, tf_box_6x.3mf, tfsik_box.scad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]
2023-08-16 projection scad
    [projection.scad]
2023-08-16 Add and update submodule for firmware and QFH antenna.
2023-08-22 Improve #18.
    [TFSIK01.kicad_sch]
2023-09-21 Improve #18
    [TFSIK01.kicad_sch, rfswitch.kicad_sch]
2023-09-22 Add notes to match ISM bands.
    [TFSIK01.kicad_sch]
2023-09-23 Add notes to TX port impedances for given frequencies.
    [TFSIK01.kicad_sch]
2023-09-23 improve pull-up inductor.
    [TFSIK01.kicad_sch]
2023-09-25 Update README.md
    add a note about difficulties with using an mismatched antenna.
2023-09-25 move led border, udptae gcodes
    [rf_shield.3mf, tf_box.3mf, tf_box_6x.3mf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]
2023-09-28 repair box - remove material above jst-gh
    [tf_box.3mf, tf_box_6x.3mf, tfsik_box.scad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]
2023-09-30 The rought version of SMA antenna holder to TFSIK modem.
    [tfsik_antenna_holder.scad, tfsik_box.scad]
2023-10-01 Tune antenna holder dimensions.
    [tfsik_antenna_holder.3mf, tfsik_antenna_holder.scad, tfsik_antenna_holder.stl]
2023-10-01 Fix SMA connectors position assymetry.
    [tfsik_antenna_holder.3mf, tfsik_antenna_holder.scad, tfsik_antenna_holder.stl]
2023-10-01 Test the 5.1.0-alpha1 Firmware for Original Prusa MINI With unclear improvement results.
    [tfsik_antenna_holder.3mf]
2023-10-01 Increase wall thickness to solve printing issues.
    [tfsik_antenna_holder.3mf, tfsik_antenna_holder.scad, tfsik_antenna_holder.stl]
2023-10-01 Add echo to determine lenght of space for frequency marking sticker.
    [tfsik_antenna_holder.scad]
2023-10-05 Remove manufacturing data.
    [tf_box_6x.3mf]
2023-10-17 Improve documentation by describing the antenna kit hardware.
2023-10-17 Update README.md
    Spell check, and describe mounting.
2025-02-03 Update project to KiCADv8.
    [TFSIK01.kicad_pcb, TFSIK01.kicad_sch, rfswitch.kicad_sch]
2025-03-16 Add antenna holder variant for cylindrical SMA connector antennas.
    [tfsik_antenna_holder.scad, tfsik_antenna_holder_SMA_cylinder.stl]
2025-03-24 Improve box disassembly.
    [tf_box.3mf, tfsik_box.scad, tfsik_box.stl]
2025-05-27 Update project to KiCAD 9. Fix issue #22
    [TFSIK01.kicad_pcb, TFSIK01.kicad_sch, rfswitch.kicad_sch]
2025-05-27 Fix DRC errors.
    [TFSIK01.kicad_pcb, TFSIK01.kicad_sch]
2025-05-28 Significantly improved RF tunning.
    [TFSIK01.kicad_pcb, TFSIK01.kicad_sch, rfswitch.kicad_sch]
2025-05-28 Update project. Fix kibot errors.
    [TFSIK01.kicad_pcb, rfswitch.kicad_sch]
2025-05-28 Update PCB from schematics.
    [TFSIK01.kicad_pcb]
2025-05-28 Update submodule.
    [TFSIK01-bom.csv, TFSIK01-bom_nogroup.csv]
2025-05-29 Improve components selection.
    [TFSIK01.kicad_pcb, TFSIK01.kicad_sch]
2025-05-29 Improve fabrication layer.
    [TFSIK01.kicad_pcb]
2026-02-15 Automatic update of KiCAD outputs
    [TFSIK01.step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]
